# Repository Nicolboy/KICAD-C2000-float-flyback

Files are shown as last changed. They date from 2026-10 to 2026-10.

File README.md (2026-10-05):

# KICAD-C2000-float-flyback

- **18.9W** — real-world target power, simulated efficiency up to 94.8%
- **+5 points** efficiency from synchronous rectification (UCC24612) vs. body-diode
- **106.8V → 61–65V** — secondary overvoltage, resolved by a TVS clamp sized through simulation (×1.5 margin vs. the 100V MOSFET rating)

Isolated, floating-secondary flyback power supply for vacuum-tube filament
heating and a low-noise preamp stage, designed in KiCad 10. 200kHz,
11–25V in → 5.5–13V/3A out, secondary floating and liftable 0–90V for
cathode/filament stress reduction. Synchronous secondary rectification
(UCC24612, direct Vds sensing — no firmware timing) validated by SPICE at
the real 18.9W target, including a secondary-side overvoltage finding and
the clamp that fixes it — see *Validation* below for the figures and
`doc/sim-vs-mesure.md` for the full data.

Alimentation flyback isolée et flottante pour le chauffage d'un filament de
tube à vide et un étage de préamplification bas bruit, conçue sous KiCad 10.

Convertisseur flyback 200kHz, 11-25V en entrée → 5,5-13V/3A en sortie.
Secondaire entièrement flottant, élevable de 0 à 90V par un pont symétrique
2×100kΩ (une résistance vers Vout+, une vers Vout-) — pour réduire le stress
cathode/chauffage sur un préamplificateur à tubes bas bruit (montage cascode).

<p align="center">
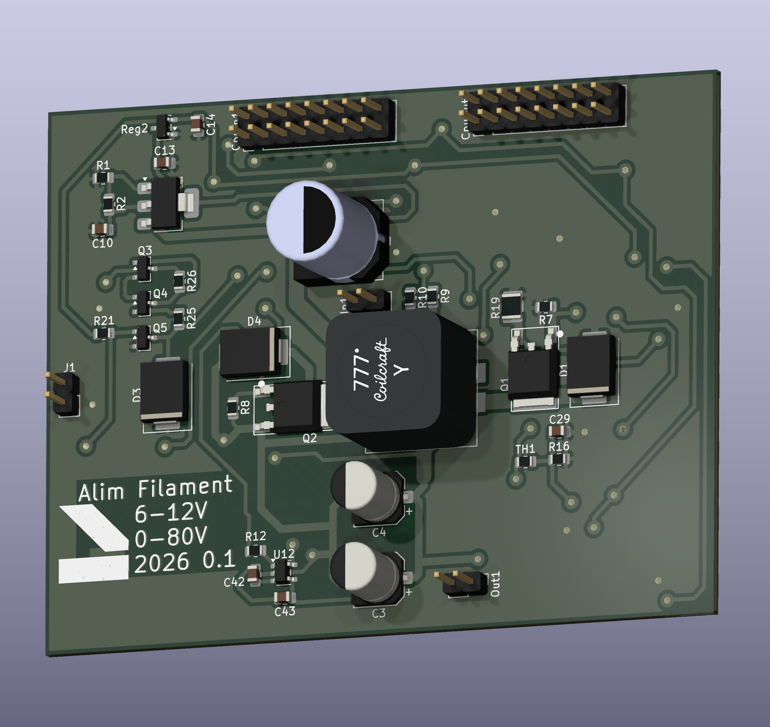
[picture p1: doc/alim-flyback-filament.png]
Rendu 3D de la carte d'alimentation flyback KiCad
  
</p>

---

## Le point de conception le plus notable

Le redressement synchrone secondaire (Q2) est piloté par un **UCC24612**, pas
par le C2000 : ce contrôleur détecte directement le Vds de Q2 (diode
emulation) et pilote sa grille tout seul — aucun signal PWM ni isolateur
dédié à faire traverser la barrière pour ce canal. Avant ça, la commande
passait par un ISO7710+UCC27517 secondaires pilotés en PWM depuis le C2000 :
un timing fixé par le firmware, « à l'aveugle », sans retour sur le vrai Vds
de Q2 — remplacé une fois ce défaut identifié. L'UCC24612 est alimenté
directement depuis Vout (VDD dans sa plage 4,5-28V, pas de bootstrap
nécessaire) ; côté primaire, l'isolation PWM/EN (ISO7710 + UCC27517 + DPC817)
reste inchangée.

Chaque composant de puissance (MOSFETs, clamp, condensateurs d'entrée et de
sortie) est sourcé avec sa propre fiche datasheet dans
[`composants-datasheets/data/carte-flyback/`](../composants-datasheets/data/carte-flyback)
— page citée, base (absolue / recommandée / typique / calculée), jamais de
valeur choisie à l'oeil. Ce sourcing a d'ailleurs fait revenir deux fois sur
le choix de Cin et Cout : le premier calcul prenait le coin 13V/3A (39W)
comme pire cas, avant d'être recorrigé sur les vrais coins d'usage — deux
câblages de filament qui tombent à **la même puissance réelle** (18,9W) et
divisent par deux la contrainte de courant et d'ondulation retenue au départ.
Le détail (formules, marges, historique des choix) est dans
[`00-intention-conception.md`](00-intention-conception.md).

---

## Architecture

| Bloc | Rôle |
|---|---|
| Primaire | Cin, MOSFET N (TO-252), clamp TVS D1 (boîtier SMC), UCC27517 + ISO7710 (PWM) |
| Isolation | ISO7710 (PWM primaire) + DPC817 (EN) — plus de canal PWM dédié au secondaire |
| Secondaire (flottant) | MOSFET N potentiel bas (rectification synchrone), UCC24612 (détection Vds, alimenté direct depuis Vout) + clamp TVS D4, banc Cout, pont bias 2×100kΩ |
| Couplage | Coilcraft MSD1514, 1:1 (k≈0,99), 10µH par enroulement |

L'isolation fonctionnelle est dimensionnée pour l'écart réel présent sur la
carte (~100V avec le bias), pas pour la tenue diélectrique complète des
isolateurs (5000V) — pas de slot d'isolation dans le PCB.

---

## Le schéma est généré, les feuilles sont ensuite routées à la main

```
00-intention-conception.md      source de vérité (calculs, marges, sourcing)
        │
        ├── gen_symboles.py        → lib/custom_parts.kicad_sym
        │                            (UCC27517, ISO7710, MSD1514, MOSFET 3 broches)
        │
        └── gen_composants.py      → alim.kicad_sch / flyback.kicad_sch /
              ▲                       isolation.kicad_sch (feuilles hiérarchiques)
              │                       kicad_gen.py — primitives communes
        étiquettes globales uniquement, aucun fil posé par script
```

Une fois qu'une feuille a été reprise à la main dans KiCad (repositionnement
des composants, rotation, déplacement des étiquettes Référence/Valeur), elle
devient un **fichier de travail permanent** : les générateurs ne sont plus
rejoués dessus.

ERC sur la hiérarchie complète des 3 feuilles : 0 erreur. Empreintes custom
(`lib_fp/*.pretty/`) pour l'inductance couplée MSD1514, le MOSFET TO-252 et le
condensateur KEMET A786MW (V-chip), toutes construites à partir des cotes
mécaniques des datasheets plutôt que d'une empreinte générique approximative.

Placement et routage du PCB restent manuels, comme pour les autres cartes de
ce workspace.

---

## Validation — simulation et mesure

| Étape | État |
| --- | --- |
| Calcul analytique | fait — [`00-intention-conception.md`](00-intention-conception.md) |
| Simulation LTspice (diode, 10W) | étapes 1-4 faites, modèles réels (MOSFET Infineon, clamp D1) |
| Simulation LTspice (18,9W, synchrone) | faite — proxy UCC24612, clamp secondaire dimensionné |
| Redressement synchrone (KiCad) | implémenté — UCC24612 (U12) + clamp D4 |
| Prototype | à fabriquer |
| Mesures au banc | à faire |

Balayage à Vin=11/20/25V, 6V et 12V à 10W (+ un point à charge légère) :
rendement 84-91%, et la tension drain de Q2 dépasse déjà 100V (sa tenue
en tension) à Vin≥23V environ, sans clamp secondaire modélisé à ce
stade.

<p align="center">
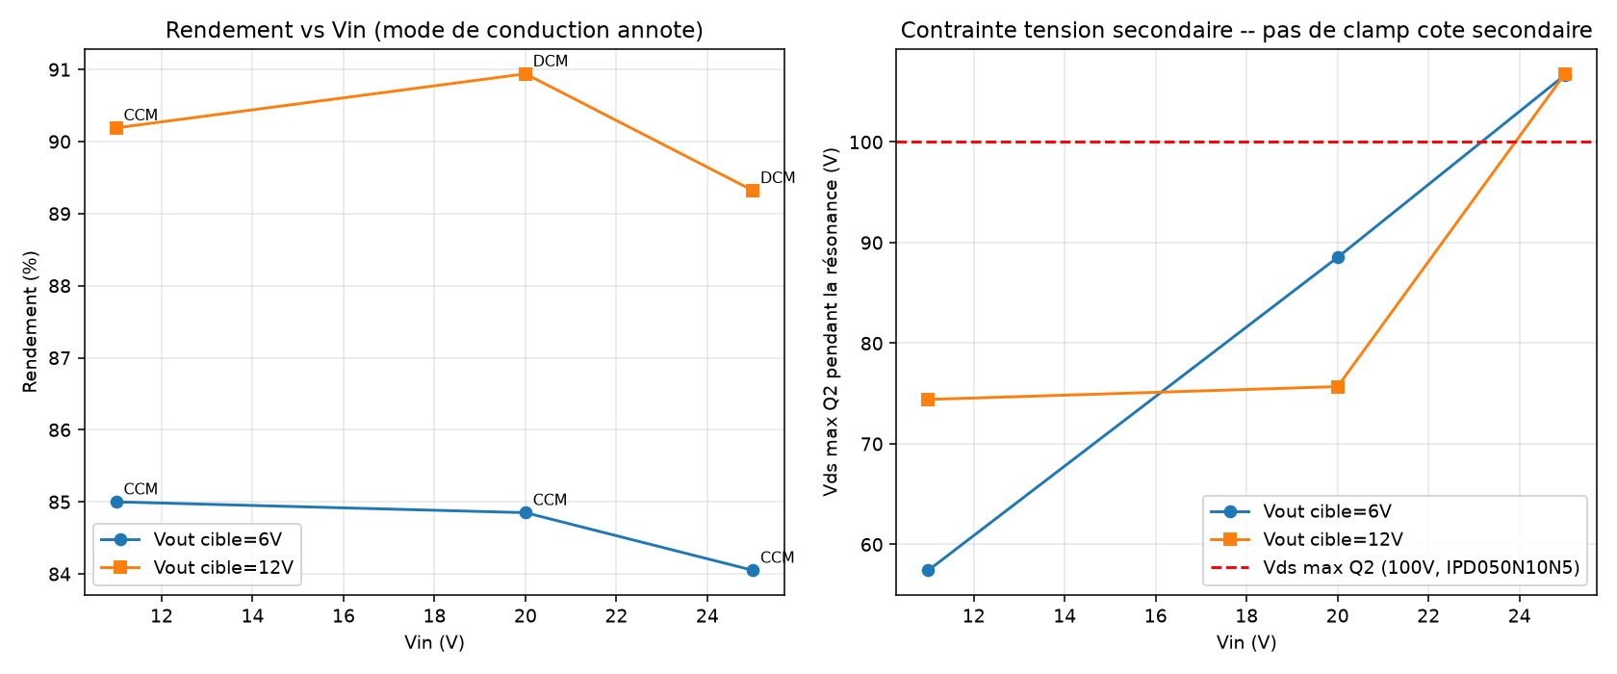
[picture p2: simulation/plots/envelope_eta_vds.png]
Rendement et Vds Q2 vs Vin, 10W, redressement par diode de corps
  
</p>

Autre résultat notable : la plupart des points réels fonctionnent en
**CCM**, pas en DCM comme une estimation rapide l'avait d'abord suggéré —
déterminé sur la forme d'onde (passage par zéro de I(L2)), pas supposé.
Comparé à un modèle Schottky générique simplifié (rapide mais pas le
composant réel) pour chiffrer la perte dans le clamp D1 :

<p align="center">
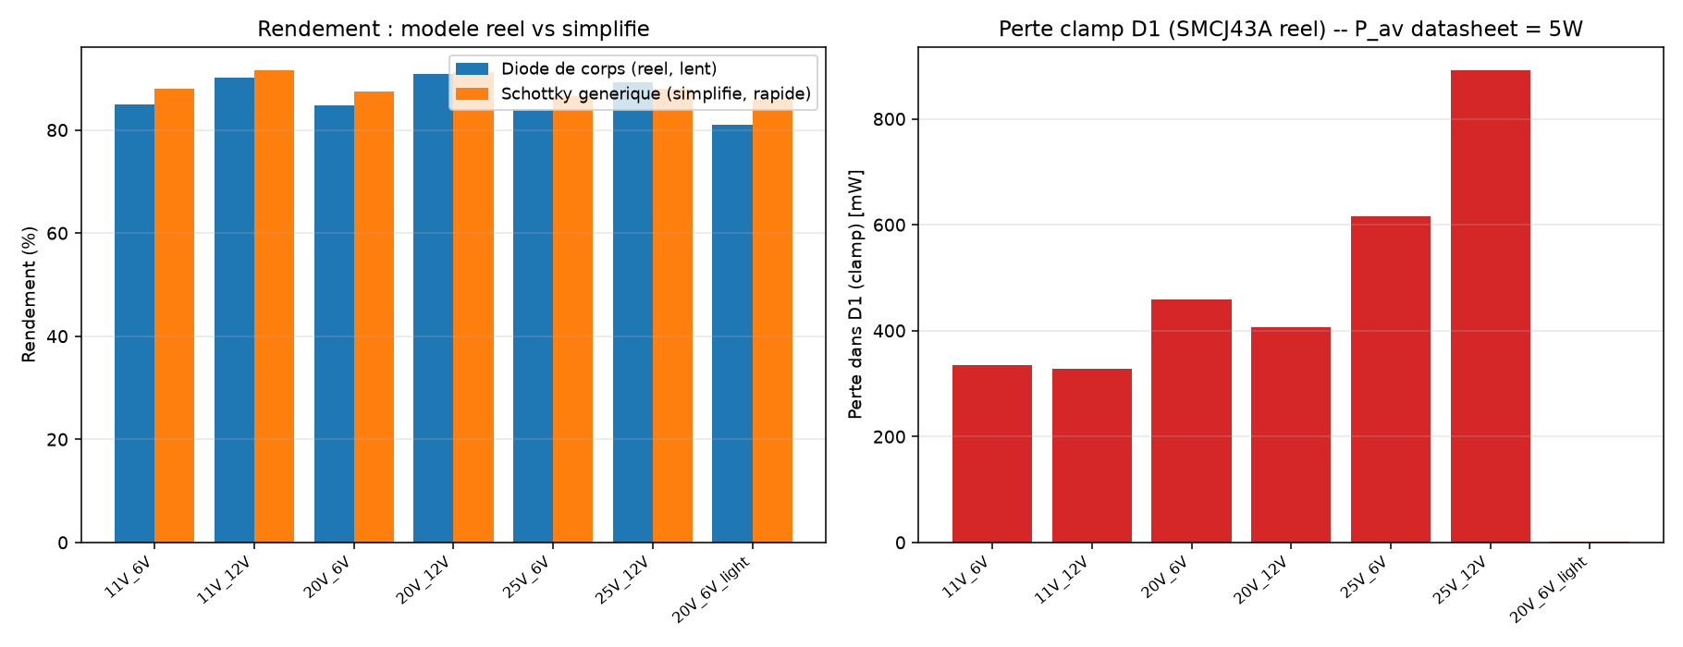
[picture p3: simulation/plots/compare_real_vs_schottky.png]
Rendement modele reel vs simplifie, et perte dans le clamp D1
  
</p>

Rejoué à la cible réelle (**18,9W**) avec un proxy de redressement
synchrone : le dépassement empire (dès Vin=20V, jusqu'à 106,8V) —
indépendant du redresseur, c'est une résonance de l'inductance de fuite.
Le passage en synchrone (UCC24612) apporte jusqu'à +5 points de
rendement, mais ne corrige pas la surtension :

<p align="center">
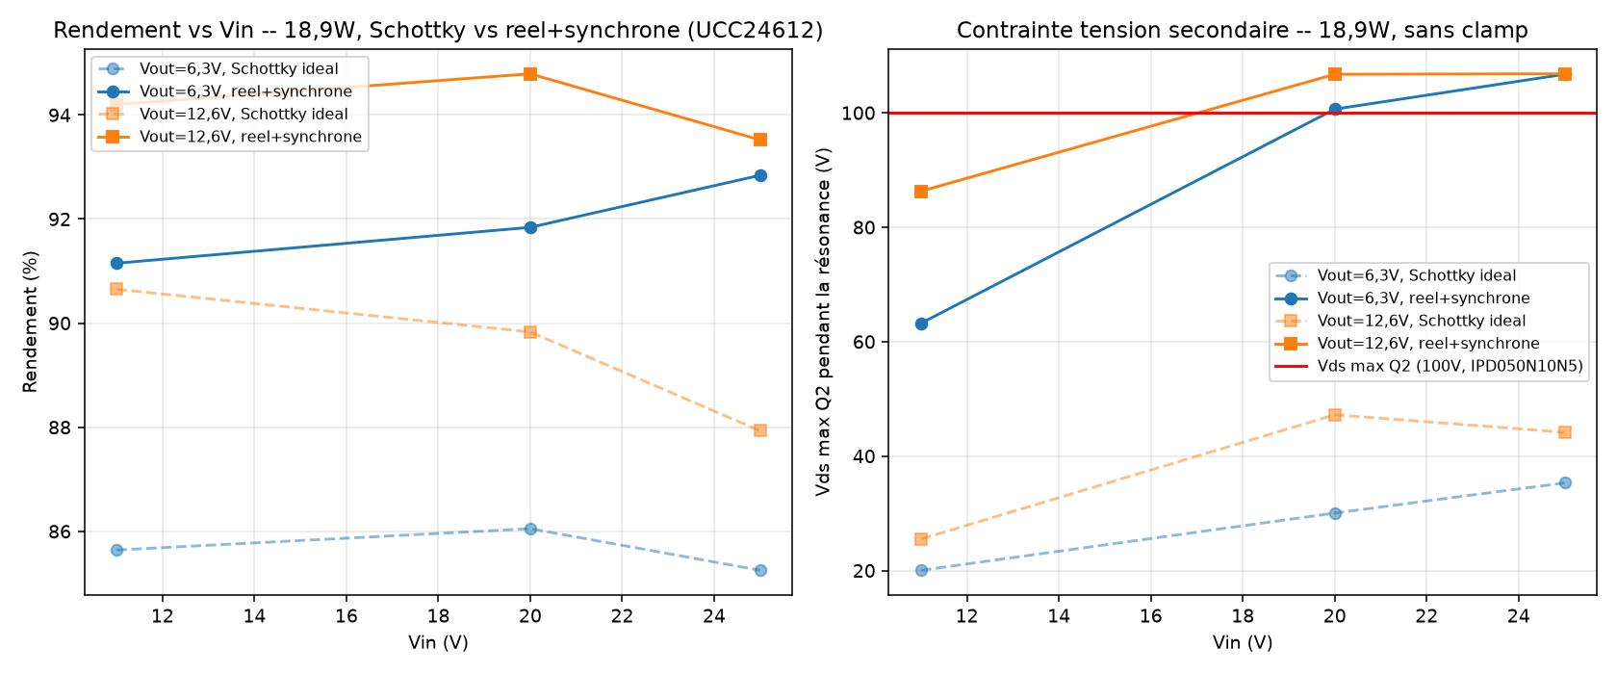
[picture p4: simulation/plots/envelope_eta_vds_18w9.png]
Rendement et Vds Q2 vs Vin, 18,9W, Schottky vs reel+synchrone
  
</p>

D'où le clamp secondaire **D4 (SMCJ54A)**, qui ramène Vds_Q2 à 61-65V
(marge ×1,5) pour 0,03-0,76W de dissipation (marge ×6,6 vs les 5W du
composant) — comparé au SMCJ43A (même réf. que D1, déjà au BOM) qui tient
aussi mais coûte jusqu'à 2 points de rendement de plus :

<p align="center">
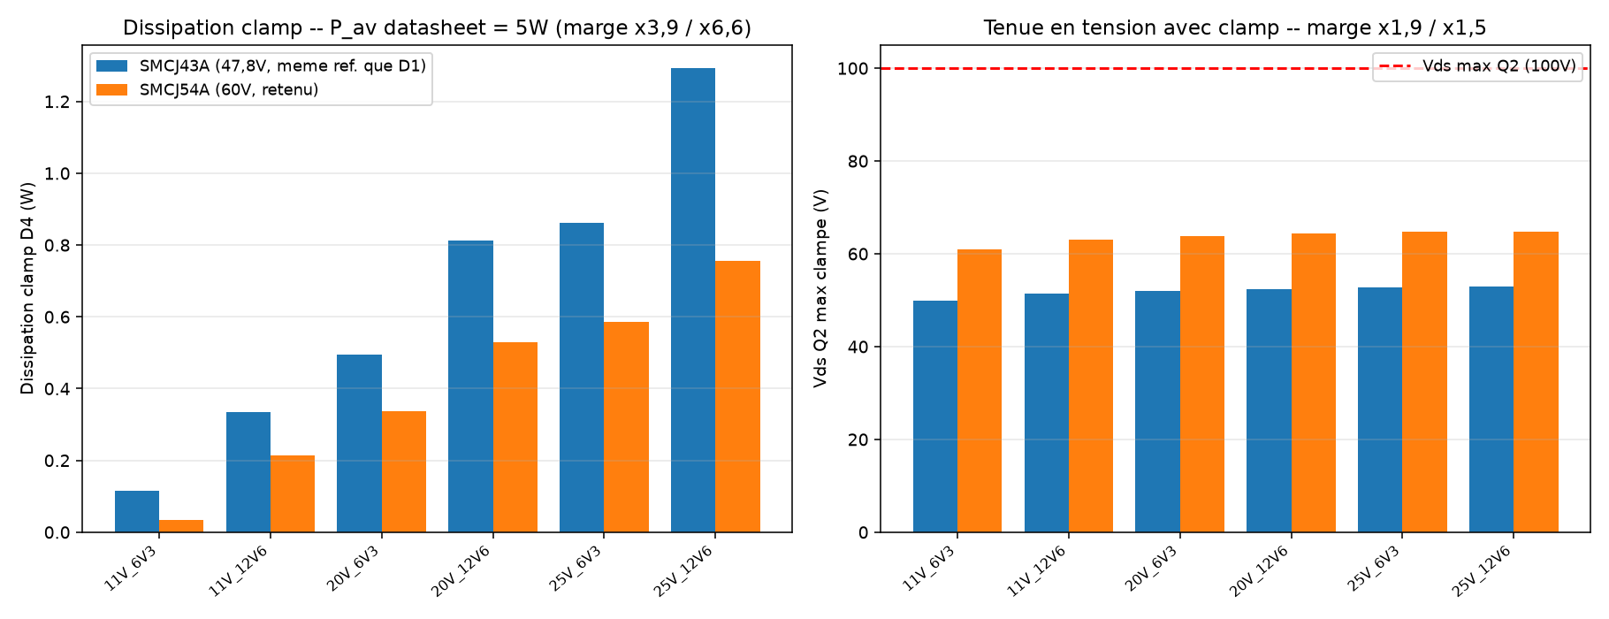
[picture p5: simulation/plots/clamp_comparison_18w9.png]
Comparaison clamp secondaire SMCJ43A vs SMCJ54A, dissipation et tenue en tension
  
</p>

Le détail, le protocole de mesure et le tableau calcul / simulation /
mesure : [`doc/sim-vs-mesure.md`](doc/sim-vs-mesure.md) (§7/§7bis pour le
passage 18,9W) ; l'implémentation KiCad correspondante :
[`00-intention-conception.md`](00-intention-conception.md) §16.

---

## Licence

CERN-OHL-S v2 — voir [`LICENSE`](LICENSE).

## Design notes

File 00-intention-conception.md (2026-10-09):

# Intention de conception — flyback flottant filament + préampli

| | |
|---|---|
| Révision | v0.8 — redressement synchrone secondaire réel : UCC24612 (U12) remplace U2/U4, clamp D4 ajouté |
| Établi le | 2026-09-28, mis à jour 2026-10-04 |
| Statut | duty cycle et courants inductance vérifiés ; clamp TVS SMC et filtrage de sortie 50mV tranchés (§6, §7) ; retour ADC isolé AMC0311S ajouté (§13) ; UCC5304 essayé puis abandonné côté secondaire, marge UVLO insuffisante pour un filament réglable (§13bis) ; retours température MOSFET/transfo et courant primaire ajoutés, isolateurs migrés vers la famille ratiométrique AMC03x1R/AMC03x2R (§14) ; isolation C2000 rendue réelle — U3/U4/U5/U7/U8/U9 migrés sur GND_CTRL/3V3_CTRL, connecteur scindé CpuOut/CpuIn (§15) ; nouvelle feuille Polarisation — HV_BIAS piloté activement 0-78V utiles depuis une source 80V externe fixe, connecteurs C2000 agrandis à 16 broches (§16) ; cible 18,9W validée par simulation sous réserve d'un clamp secondaire, U2(UCC27517)+U4(ISO7710) remplacés par U12(UCC24612, détection Vds) + D4(SMCJ54A) (§17) |

Convention reprise de `composants-datasheets/CLAUDE.md` : `spec` = exigence
d'entrée · `déduit` = calculé · `?` = à trancher. Toute valeur `déduit` porte
sa formule et sa source.

## 1. Fonction

Flyback isolé flottant, 200kHz, alimentant un filament de chauffage tube +
étage de préamplification bas bruit. Secondaire flottant, élevable de 0 à
90V par pont 2×100k symétrique (Vout+/Vout- vers la source HV externe).

## 2. Grandeurs par nœud

| Nœud | Nominal | Max | Statut |
|---|---|---|---|
| `Vin` | 11 – 25 V | 25 V | spec |
| `Vout` | 5,5 – 13 V | 13 V | spec |
| `Iout` | — | 3 A | spec |
| `f_sw` | 200 kHz | — | spec |
| Bias secondaire (vers HV externe, 2×100k) | 0 – 90 V | 90 V | spec |

**Charge réelle — spec.** 10 filaments de tube préampli standard (12AX7 ou
EF86), câblage variable :

| Câblage | Vout | Iout | Pout |
|---|---|---|---|
| Parallèle | 6,3 V | 3 A | 18,9 W |
| Série (paires) | 12,6 V | 1,5 A | 18,9 W |

Les deux corners tombent à la **même puissance** (charge résistive de
filament à puissance constante). C'est ce couple qui pilote les calculs de
courant et de dissipation ci-dessous — **pas** le coin 13V/3A (39W) utilisé
en v0.1, qui surestimait largement la contrainte réelle. Le plafond `Vout
max = 13V` de la spec reste néanmoins la référence pour le dimensionnement
en **tension** (§5) : rien n'indique que 13V soit exclu, seulement que le
courant n'y atteint pas 3A dans l'usage prévu.

## 3. Étage primaire — duty cycle et courants

Coupled inductor MSD1514-103ME, 1:1 (k≈0,99), L=10µH chaque enroulement —
`datasheets/inductors/msd1514.pdf` p.2, tbl produit.

Rapport cyclique (1:1, pertes de diode ignorées au premier ordre) :
`D/(1-D) = Vout/Vin`

| Vin | Vout | D | Statut |
|---|---|---|---|
| 25 V | 6,3 V | 0,201 | déduit |
| 11 V | 12,6 V | 0,534 | déduit |
| 11 V | 6,3 V | 0,364 | déduit |

**Coin de pire cas retenu pour le courant primaire : Vin=11V (le plus
défavorable, courant d'entrée le plus élevé à puissance donnée), comparé
sur les deux câblages réels.**

Hypothèse de rendement **η=0,85** — **non sourcée, à vérifier au banc**,
basis: computed/assumed. C'est l'hypothèse la plus sensible de ce paragraphe.
Pin = 18,9 / 0,85 = 22,24 W dans les deux cas (même Pout).

```
                              Câblage 6,3V/3A    Câblage 12,6V/1,5A
D (à Vin=11V)                 0,364               0,534
Iin_avg = Pin/Vin              2,02 A              2,02 A
I_on_avg = Iin_avg/D            5,55 A              3,79 A
ΔI = Vin×D×T/L                  2,00 A              2,94 A
Ipk = I_on_avg + ΔI/2            6,55 A              5,25 A
Ivalley = I_on_avg − ΔI/2         4,55 A              2,32 A
I_on_rms                          5,58 A              3,88 A
I_primaire_rms = I_on_rms×√D        3,37 A              2,84 A
```

**Le câblage 6,3V/3A est le coin le plus contraignant** (Ipk et Irms les
plus élevés) — c'est lui qui pilote le clamp (§6) et le MOSFET primaire.

**Vérification vs MSD1514-103ME.** Le datasheet donne deux colonnes Irms :
« both windings » (5,4A) et « one winding » (7,6A) — la première vise les
topologies à conduction simultanée des deux enroulements (SEPIC/Zeta,
diagrammes typiques du même datasheet p.1), la seconde le flyback où les
deux enroulements conduisent en alternance, jamais ensemble. **C'est la
colonne « one winding » qui s'applique ici** (le flyback est un des schémas
typiques donnés pour ce composant, doc 1308-1 p.1).

| | Calculé (coin 6,3V/3A) | Limite (one winding) | Marge |
|---|---|---|---|
| Irms primaire | 3,37 A | 7,6 A | ×2,26 |

Marge large, pas de point dur sur l'inductance côté courant. Isat au pire
cas (Ipk=6,55A) est très en dessous de Isat-10% (12,2A) — pas de
saturation.

## 4. Étage secondaire — courants

Secondaire 1:1, conduction complémentaire du primaire (jamais simultanée).
Par continuité du flux (couplage k≈0,99), le courant secondaire démarre à
Ipk et redescend à Ivalley sur la durée (1-D)×T. Au coin dimensionnant
(6,3V/3A, Vin=11V, D=0,364) :

```
I_off_rms = même formule que I_on_rms = 5,58 A  (mêmes Ipk/Ivalley, durée différente)
I_secondaire_rms = I_off_rms × √(1-D) = 5,58 × √0,636 = 4,45 A
```

| | Calculé | Limite (one winding) | Marge |
|---|---|---|---|
| Irms secondaire | 4,45 A | 7,6 A | ×1,71 |

## 5. Contrainte en tension MOSFET primaire

Dimensionnement en **tension** : référencé au plafond de spec (13V), pas
au coin de charge réel — la tenue en tension ne dépend pas du courant tiré
à cette tension.

```
Vds_regime = Vin_max + Vout_max_reflected(1:1) + Vf_redresseur
           = 25 + (13 + 1) = 39 V     (Vf=1V, hypothèse diode de corps en phase bootstrap)
```

Reste à ajouter la surtension de commutation due à l'inductance de fuite
(0,40µH typ, même tableau datasheet) — voir §6, elle fixe le niveau de
clamp et donc la tenue en tension à viser pour le MOSFET.

## 6. Clamp primaire — TVS SMC, tranché

Énergie de fuite par cycle, au coin de charge réel dimensionnant
(6,3V/3A, Ipk=6,55A — §3) :

```
E_fuite = ½ × L_fuite × Ipk² = 0,5 × 0,40µH × 6,55² = 8,59 µJ
P_clamp = E_fuite × f_sw = 8,59µJ × 200kHz ≈ 1,72 W
```

Nettement plus raisonnable que l'estimation v0.1 (3,4W, basée sur le coin
13V/3A surestimé). **1,7W est tenable par un TVS en boîtier SMC/DO-214AB**
avec un cuivre de dissipation correct — décision retenue : **TVS/zener,
boîtier SMC**. Tension de claquage à sourcer pour couvrir les 39V de
Vds_regime (§5) avec marge de clamp, sans dépasser la tenue en tension du
MOSFET primaire retenu.

## 7. Filtrage de sortie — banc de condensateurs, tranché

Cible relâchée à **50mV** d'ondulation crête-crête max (décision utilisateur),
Iout et D pris au coin de charge réel dimensionnant (6,3V/3A, D=0,364,
Ipk=6,55A — §3, plus contraignant que 12,6V/1,5A).

**Composante capacitive** (le cap seul alimente la charge pendant Ton) :
```
ΔQ = Iout × D × T = 3 × 0,364 × 5µs = 5,46 µC
Pour ΔV_C = 20mV (part du budget) : C = ΔQ / ΔV_C ≈ 273 µF
```

**Composante ESR** (démonstration : le saut de courant dans le
condensateur vaut Ipk à l'ouverture, Ivalley à la fermeture — le premier
domine ; ΔV_ESR,pk-pk = ESR × Ipk, formule standard flyback, pas les 9,2A
de battement grossièrement estimés en v0.1) :
```
Pour ΔV_ESR = 30mV (reste du budget) : ESR_max = 30mV / 6,55A ≈ 4,6 mΩ
```

**4,6mΩ est atteignable par un petit banc de condensateurs polymère bas
ESR en parallèle** (ESR unitaire typique 10-15mΩ en boîtier CMS courant →
2 à 3 en parallèle suffisent, ESR combiné = ESR_unitaire / N). Décision
retenue : **banc de 2-3 condensateurs polymère CMS en parallèle**, cible
combinée ESR ≤ 4,6mΩ et C ≥ 273µF. Références précises à sourcer (§ sourcing
composants).

## 8. Condensateurs — Cin, Cout, Cboot, tranchés

**Cin** (entrée, coin de charge réel 6,3V/3A, D=0,364, §3) :

```
I_on_rms = 5,58A, I_on_avg = 5,55A  (§3)
Icin_rms = √(D×(I_on_rms² − D×I_on_avg²))
         = √(0,364×(5,58² − 0,364×5,55²)) = 2,69A
```

Première solution retenue : 2× UCM1V222M1MS (Nichicon UCM, 2200µF/35V,
45mΩ) — 4,12A de marge ripple mais 22,5mΩ combiné, soit ~149mV
d'ondulation d'entrée réelle (calcul complet ci-dessous, pas de cible
formelle contrairement à la sortie). **Remplacée** (utilisateur,
2026-09-29) par **1× KEMET A786MW477M1VLAV010** (hybride polymère,
470µF/35V, ESR=10mΩ) —
`composants-datasheets/data/carte-flyback/a786mw477m1vlav010.yaml` :

```
ΔV_ESR = 10mΩ × 6,553A (Ipk, §3)                         ≈ 65,5mV
ΔV_C   = (I_on_avg−Iin_avg)×D×T / C = 3,532A×0,364×5µs/470µF ≈ 13,7mV
Total  ≈ 79,2mV — contre 148,9mV avec l'ancienne solution (2×UCM)
```

Un seul exemplaire suffit (comparé à l'option 2× qui donnait 39,6mV — écartée
par l'utilisateur au profit d'un seul composant). Ripple current très
large marge (5,6A@125°C vs 2,69A requis, ×2,08). Marge tension ×1,4 (35V
vs 25V Vin_max), identique à l'ancienne solution.

**Cout** (sortie, cible relâchée à 50mV — décision utilisateur du
2026-09-28, coin de charge réel 6,3V/3A, Ipk=6,55A, D=0,364, §3) :

```
ΔQ = Iout×D×T = 3×0,364×5µs = 5,46µC
ΔV_ESR(N) = (ESR_unitaire/N) × Ipk        ΔV_C(N) = ΔQ/(C_unitaire×N)
```

Un électrolytique « low impedance » classique (famille UCM, ~24-45mΩ pour
un gros boîtier) ne permet pas d'approcher l'ESR combiné visé sans un
nombre de boîtiers déraisonnable. Première solution retenue (5×
Panasonic 25SVPF100M, 100µF/25V, ESR=24mΩ) donnait 42,4mV — marge 15%
seulement. **Remplacée** (utilisateur, 2026-09-29) par **2× Panasonic
16SVPG330M** (330µF/16V, ESR=6,5mΩ — le plus bas de sa série) —
`composants-datasheets/data/carte-flyback/16svpg330m.yaml` :

```
ΔV_ESR = (6,5mΩ/2)×6,55A ≈ 21,3mV
ΔV_C   = 5,46µC/660µF    ≈ 8,3mV
Total  ≈ 29,6mV < 50mV — marge 41%. (N=1 donne 59,1mV, insuffisant.)
```

Moins de composants (2 au lieu de 5), meilleure marge d'ondulation, mais
marge en tension plus courte : 16V vs Vout_max=13V = ×1,23 (23%), contre
×1,92 pour l'ancienne solution — acceptée explicitement par l'utilisateur
après avoir vu le calcul.

**Cboot — composant retiré (§17, 2026-10-04), calcul conservé pour mémoire.** (stockage bootstrap secondaire, alimentait UCC27517-secondaire en direct + MCP1703 en amont de l'ISO7710-secondaire — architecture validée avec l'utilisateur en amont de cette session)
direct + MCP1703 en amont de l'ISO7710-secondaire — architecture validée
avec l'utilisateur en amont de cette session) :

```
Qg(IPB020N10N5) = 210nC (max, composants-datasheets/data/carte-flyback/ipb020n10n5.yaml)
Iq(UCC27517+MCP1703+ISO7710) ≈ 5mA (ordre de grandeur, non individuellement sourcé)
Intervalle de décharge = Ton (primaire) au pire cas = D×T = 0,364×5µs = 1,82µs
ΔQ ≈ Qg + Iq×Ton ≈ 210nC + 5mA×1,82µs ≈ 219nC
Pour ΔV_droop = 200mV (marge sous l'hystérésis UVLO UCC27517, 300mV typ) :
C_boot = ΔQ/ΔV ≈ 1,1µF minimum
```

Retenu : **4,7µF X7R 0805, 25V** — céramique standard (pas de fiche
sourcée séparée : composant passif générique, cohérent avec la pratique du
reste du dépôt pour le découplage). Marge large même avec déclassement en
tension continue typique du X7R (effective ~2-3µF sous polarisation
~6-12,5V, encore ≥ le minimum calculé).

## 9. Alimentation auxiliaire primaire — ajout non prévu dans la spec initiale

En construisant le schéma, un trou est apparu : rien n'alimente l'UCC27517
et l'ISO7710 côté **primaire** (référencé masse, pas de problème de
flottement contrairement au secondaire, mais Vin=11-25V dépasse la plage
recommandée de l'UCC27517 — 4,5-18V — et l'absolu de l'ISO7710 — 5,5V max).
Il faut une alim auxiliaire primaire, absente de la spec initiale.

Repris à l'identique du montage déjà en service sur l'autre carte de ce
workspace (`00-intention-conception-v12.md` §7/§10, dual-boost) : **LM317M
+ pont 100Ω/560Ω → 8,25V** pour l'UCC27517-primaire (`data/carte-puissance/
lm317m.yaml`, déjà sourcé — repris pour `carte-flyback` avec ses propres
repères), puis **MCP1703-3302 en cascade depuis ce rail 8,25V** (déjà
sourcé pour le secondaire, `data/carte-flyback/mcp1703.yaml`) → 3,3V pour
l'ISO7710-primaire. Deux avantages à cascader plutôt que deux régulateurs
depuis Vin directement : le MCP1703 n'a plus à encaisser les 25V de Vin_max
(son propre Vin_max est 16V, insuffisant en direct), et aucun nouveau
composant à sourcer.

```
Vout(LM317M) = 1,25×(1+R2/R1) = 1,25×(1+560/100) = 8,25V   (mêmes valeurs que l'autre carte)
Différentiel au point bas : Vin_min − Vout = 11 − 8,25 = 2,75V
```

Sous le dropout min publié (3,0V, `lm317m.yaml`) — **même marge que l'autre
carte**, qui traite déjà ce point comme acceptable (« clôt la question du
dropout » dans son propre document d'intention). Pas retranché ici.

Dissipation estimée (Q1 Qg=72nC×200kHz≈14,4mA + ISO7710 primaire ~1,7mA +
marges ≈20mA) : P=(25−8,25)×20mA≈0,34W. Avec Rth_ja=245°C/W (boîtier
SOT-223, empreinte minimale — même valeur élevée déjà notée comme
suspecte sur l'autre carte) : ΔT≈82°C, Tj≈107°C à 25°C ambiant — chaud
mais sous Tj_max=150°C. Cuivre de dissipation à soigner au routage, comme
sur l'autre carte.

## 10. Composants sourcés — récapitulatif

| Rôle | Réf. | Composant | Fiche |
|---|---|---|---|
| MOSFET primaire+secondaire | Q1, Q2 | IPD050N10N5 (TO-252/DPAK, 100V, 5mΩ) | `data/carte-flyback/ipd050n10n5.yaml` |
| Empreinte Q1/Q2 | — | `lib_fp/TO252.pretty/TO252-3_TabPin2.kicad_mod`, custom (3 pastilles, cotes Figure 1 du datasheet IPD050N10N5 fournies par l'utilisateur) — remplace la générique KiCad jugée peu lisible (4 pastilles). **Pin1(Gate)/Pin3(Source) permutées (2026-10-01)** — voir point ouvert résolu ci-dessous. Modèle 3D (2026-10-01) : d'abord le `.step` fourni avec KiCad (miroir corrigé par `scale -1 1 1`), puis **remplacé** par `composants-datasheets/datasheets/to_252_2.step` (step.parts.com, 3 broches + tab, boîtier compact — fourni par l'utilisateur). Transform identité par défaut, alignement à confirmer dans le visualiseur 3D (pas de rendu possible de mon côté) |
| Clamp primaire | D1 | SMCJ43A (SMC/DO-214AB) | `data/carte-flyback/smcj43a.yaml` |
| Rail 8,25V primaire | Reg1 | LM317M (SOT-223) + R1=100Ω/R2=560Ω | `data/carte-flyback/lm317m.yaml` |
| LDO ISO7710 primaire | Reg2 | MCP1703-3302 (SOT-23A, 3,3V) | `data/carte-flyback/mcp1703.yaml` |
| LDO auxiliaire secondaire | Reg3 | MCP1703-3302 (SOT-23A, 3,3V) — VI depuis VOUT_P direct (§17), alimente VDD1 de U7 (AMC0311R) | `data/carte-flyback/mcp1703.yaml` |
| Cin | C1 | A786MW477M1VLAV010 (KEMET, 470µF/35V, 10mΩ) | `data/carte-flyback/a786mw477m1vlav010.yaml` |
| Cout | C3, C4 | 2× Panasonic 16SVPG330M (330µF/16V, 6,5mΩ) | `data/carte-flyback/16svpg330m.yaml` |
| Ampli isolé retour Vout | U7 | AMC0311R (DWV-8, ratiométrique) — retour Vout isolé vers C2000 (§13, renommé depuis AMC0311S en §14) | à sourcer (`composants-datasheets/data/carte-flyback/amc0311r.yaml`, session dédiée) |
| Empreinte U7/U8/U9 | — | `lib_fp/SOIC_DWV.pretty/SOIC-8_DWV_5.85x11.5mm_P1.27mm.kicad_mod`, custom (boîtier DWV renforcé, cotes land pattern fournies par l'utilisateur) — modèle 3D `DWV0008A.stp` fourni par l'utilisateur, transform identité à affiner (§14) |
| Thermistance temp. primaire | TH1 | NTC 10k/B=4000, 0805 | non sourcé séparément (§14) |
| Ampli isolé retour température | U8 | AMC0311R (DWV-8, ratiométrique) — retour température primaire isolé vers C2000 (§14) | à sourcer |
| Shunt courant primaire | R19 | 1210, valeur provisoire 7,5mΩ | à sourcer (valeur et dissipation, §14) |
| Ampli isolé retour courant | U9 | AMC0302R (DWV-8, ratiométrique, ±50mV) — retour courant primaire isolé vers C2000, protection surcourant Q1 (§14) | à sourcer |
| Redressement synchrone secondaire | U12 | UCC24612 (SOT23-5) — remplace U2(UCC27517)+U4(ISO7710), détection Vds (§17) | à sourcer (`datasheets/ucc24612.pdf` déjà présent, pas encore de yaml) |
| Clamp secondaire | D4 | SMCJ54A (SMC/DO-214AB, même boîtier/famille que D1) — dimensionné `doc/sim-vs-mesure.md` §7bis (§17) | à sourcer (`datasheets/bourns-smcj-series.pdf` déjà présent, pas encore de yaml) |
| Découplage U12 | C42, C43 | 2,2µF (REG) + 100nF (VDD, bypass HF local) (§17) | non sourcé séparément, générique comme Cboot |

## 11. Points ouverts

- [ ] Rendement η=0,85 utilisé en §3 — hypothèse, à vérifier au banc
- [ ] Vf du redresseur secondaire en phase bootstrap (§5) — 1V pris par
      hypothèse. IPD050N10N5 (sourcé, Q2) donne Vf_body_diode=1,2V max à 40A
      (très au-dessus du courant réel ~6,55A) — conforte l'hypothèse comme
      raisonnablement conservatrice.
- [x] Diode de bootstrap secondaire (Vout → Cboot) — **devenue sans objet** :
      Cboot et le bootstrap associé sont retirés (§17), Reg3 (MCP1703) est
      câblé directement sur VOUT_P, plus de diode ni de chute Vf dans ce
      chemin
- [x] **Pin1(Gate)/Pin3(Source) de l'empreinte TO252-3_TabPin2 étaient
      permutées** (2026-10-01) — la réserve initiale du fichier
      d'empreinte (« pin1=haute/pin3=basse, pas confirmé par capture
      photo ») était fondée. L'utilisateur a fourni un croquis Infineon
      TO220/DPAK (languette en haut, broches 1-2-3 gauche-à-droite,
      1=Gate/2+tab=Drain/3=Source). Recalcul géométrique : en tournant la
      pièce réelle pour amener la languette à gauche (notre disposition),
      Gate doit tomber en bas-droite et Source en haut-droite — l'inverse
      de ce qui était posé. Pastilles 1 et 3 permutées (tab/pin2 inchangé).
      **À confirmer malgré tout sur pièce réelle avant premier reflow**,
      même règle que pour toute empreinte custom de ce dépôt (R15,
      `composants-datasheets/CLAUDE.md`).
- [x] Pertes de conduction Q1/Q2 — résolu par le passage en TO-252
      (IPD050N10N5, 2026-09-28) : Rds_on max 5mΩ contre 77mΩ pour l'ancien
      IRF540S. Pertes recalculées négligeables (~113-198mW, ΔT≈15°C même en
      empreinte minimale) — l'ancien point dur (1,75W, proche de la limite
      D2PAK) n'existe plus.
- [ ] Snubber/clamp éventuel côté secondaire (Q2 voit aussi une surtension
      de commutation, cf. plan initial) — pas encore traité, à revoir avant
      le routage final
- [x] Empreinte MSD1514 — corrigée (`lib_fp/MSD1514.pretty/MSD1514.kicad_mod`)
      à partir d'un crop fourni par l'utilisateur du « Recommended Land
      Pattern » (doc 1308-3 p.3), lu directement plutôt que ré-interprété
      depuis une vue pleine page. Mes deux premières lectures (pastilles
      4,2×2,8mm, différentes valeurs de pas) étaient fausses. Valeurs
      retenues : **pastilles carrées 3,7×3,7mm, pas X=7,9mm/Y=6,0mm**,
      dérivées de gapX=4,2mm/gapY=2,3mm avec vérification croisée
      (pitch−gap = 3,7mm des deux côtés). Numérotation
      pin3=haut-gauche/pin2=haut-droite/pin4=bas-gauche/pin1=bas-droite,
      lue sur ce même diagramme — **toujours pas confirmée par capture
      photo de la pièce réelle**, à vérifier avant le premier reflow (même
      discipline que R15 de `composants-datasheets/CLAUDE.md`).
- [x] Empreinte A786MW477M1VLAV010 (Cin) — corrigée quatre fois par
      l'utilisateur (2026-09-29) : (1) confusion D×L=footprint vs corps
      cylindrique (V-chip monté vertical, D=10mm de diamètre, L=16,7mm de
      HAUTEUR, pas une dimension de pastille), (2) pas pastilles affiné
      4,6→7,6mm, (3) rectangle à coins coupés ajouté — mal placé au
      premier essai (autour de la pastille), (4) corrigé : le rectangle
      chanfreiné représente l'**implantation totale du composant**
      (10,3×10,3mm, coins coupés côté positif), superposé au cercle D10mm
      (le corps cylindrique) — deux silhouettes silkscreen distinctes, pas
      un contour de pastille. `lib_fp/A786.pretty/A786MW_VChip.kicad_mod`.
- [x] Empreinte MSD1514 — corrigée deux fois (2026-09-29) : première
      lecture du land pattern (pastilles 3,7×3,7mm, pas 7,9×6,0mm)
      fausse ; cotes réelles pastilles 4,6×2,5mm, pas X=12,6mm/Y=3,8mm
      (Y affiné de 3,5 à 3,8mm) — le pas X dépasse le corps 15×15mm
      (pattes gull-wing débordant du corps, normal pour ce boîtier),
      courtyard élargi en conséquence. Numérotation des broches inchangée
      (pin3=HG/pin2=HD/pin4=BG/pin1=BD).
- [ ] Polarité du point de couplage L2 (pin2 vs pin4 du MSD1514, §
      symboles) déduite par symétrie du schéma simplifié du datasheet, pas
      explicitement marquée — à confirmer sur pièce réelle avant simulation.
- [x] Marge VDD de l'UCC5304 au coin bas — **résolu en revenant à
      ISO7710+UCC27517 sur le secondaire** (§13bis) : le plancher réel
      d'usage n'est pas 6,3V mais jusqu'à 5,8V (filament réglable -5 à
      -10% sur 6,3V nominal), ce qui aurait mis VBOOT sous le seuil UVLO
      *garanti* (pas juste recommandé) de l'UCC5304 — voir calcul précis
      §13bis avec les seuils UVLO réels du datasheet (p.8 tbl 6.9).
- [ ] Valeurs du filtre RC en sortie de l'AMC0311S (R15=100Ω, C24=1nF,
      §13) — proposées par défaut (fc≈1,6MHz, n'entame pas la bande
      passante propre de l'ampli ~120kHz), à revoir une fois la spec
      d'entrée de l'ADC côté C2000 connue.
- [ ] R11/R12 (résistances de grille en sortie des UCC, 1Ω/0805) — valeur
      retenue par l'utilisateur directement dans KiCad, pas de calcul de
      dimensionnement tracé ici (amortissement/EMI, ordre de grandeur
      courant pour ce type d'application).

- [ ] **R19 sature l'AMC0302R au coin dimensionnant** — R19 × Ipk = 7,5mΩ × 6,55A ≈ 49,2mV contre ±50mV de pleine échelle (marge 1,6%), au régime nominal retenu comme dimensionnant (§3). U9 sert à la protection surcourant de Q1 (§14) : il doit voir au-dessus du pic nominal pour détecter un défaut, pas s'écrêter dessus. À trancher : R19 plus faible (ex. 5mΩ → 32,8mV, marge ×1,52, dissipation 57mW) ou plage AMC0300R/AMC0202R (±250mV) avec le shunt actuel — pas encore choisi.
- [ ] **Plage de `HV_BIAS` — spec 0-90V (§2) non atteignable avec le rail 80V retenu** (§16) : le courant de polarisation tombe à ~0 au-delà de ~78V (§16bis), accepté explicitement pour le comportement de la source mais pas reporté dans le tableau de spec, qui affiche toujours 90V. D3 (SMCJ100A) clampe à 100V — marge à revérifier contre la valeur retenue. À trancher : abaisser la spec à ~78V, ou lever le rail `HV80_IN` au-dessus de 90V + marge.

## 12. État du projet KiCad

Schéma généré par script (`gen_composants.py`, méthode reprise de
KICAD-C2000-devkit : étiquettes globales uniquement, aucun fil, empreintes posées
sur l'instance). **Restructuré en feuilles hiérarchiques** sur demande de
l'utilisateur (2026-09-28) : une feuille racine (`alim-flyback-filament.kicad_sch`,
3 blocs `(sheet ...)`) + trois sous-feuilles —

| Feuille | Fichier | Contenu | Composants |
|---|---|---|---|
| Alimentation | `alim.kicad_sch` | Connecteurs, Reg1/Reg2/Reg3 (LDO), PWR_FLAG | 17 (initial) |
| Flyback | `flyback.kicad_sch` | Cin, T1, Q1/Q2, clamp D1, bootstrap D2/C8, Cout | 15 (initial) |
| Isolation_Drivers | `isolation.kicad_sch` | UCC27517×2, ISO7710×2, DPC817 (initial) | 9 (initial) |

Les étiquettes globales se relient à travers toute la hiérarchie sans rien
changer au câblage — le découpage est purement organisationnel, suit la
frontière fonctionnelle (et pour partie la frontière d'isolement primaire/
secondaire) plutôt que la connectivité.

**Depuis (2026-09-30), les 3 feuilles sont des fichiers de travail
hand-edited** (placement, câblage et réorganisation faits à la main dans
KiCad par l'utilisateur, plus jamais régénérés par script) — voir §13 pour
le détail des changements les plus récents (UCC5304, AMC0311S, Cpu1).
Composants redistribués entre feuilles par l'utilisateur au passage :
`J1→In1`, `J3→Out1`, `J4→Bias1` (renommés), `Reg3/C11/C12/R9/R10` déplacés
vers Flyback, `J2→Cpu1` déplacé vers Isolation_Drivers, `C1` déplacé vers
Alimentation — connectivité inchangée (les étiquettes globales ignorent la
feuille physique), seule l'organisation visuelle a bougé.

PCB généré avec contour de carte (70×55mm, à ajuster) — placement et
routage sont les étapes manuelles suivantes, comme pour les autres cartes
de ce workspace.

Fichiers : `alim-flyback-filament.kicad_pro/.kicad_sch/.kicad_pcb`,
`lib/custom_parts.kicad_sym`, `kicad_gen.py`, `gen_symboles.py`,
`gen_composants.py` (génération initiale, ne plus rejouer sur les feuilles
hand-edited).

**Modèles 3D des empreintes custom (2026-10-01)** : les trois empreintes
custom (Q1/Q2, T1, C1) ont chacune un `.step` référencé dans leur bloc
`(model ...)`. Source de chaque fichier :
- Q1/Q2 (`TO252.pretty`) : `composants-datasheets/datasheets/to_252_2.step`
  (step.parts.com, 3 broches + tab, boîtier compact)
- T1 (`MSD1514.pretty`) : `composants-datasheets/datasheets/inductors/MSD1514.STEP`
  (modèle fabricant Coilcraft, téléchargé par l'utilisateur), rotation
  `(rotate (xyz 270 0 90))` nécessaire pour le redresser
- C1 (`A786.pretty`) : `composants-datasheets/datasheets/capacitors/A786MW477M1VLAV010.step`
  (modèle Mouser/SamacSys, téléchargé par l'utilisateur)

Alignement vérifié visuellement dans KiCad par l'utilisateur au fur et à
mesure — pas de rendu 3D possible côté agent, uniquement validation
syntaxique (`kicad-cli fp export svg`).

## 13. Secondaire UCC5304 + retour Vout isolé AMC0311S (2026-09-30)

Deux changements demandés par l'utilisateur, ajoutés par édition
chirurgicale de `isolation.kicad_sch` (suppression/ajout de blocs ciblés,
jamais de régénération — voir note ci-dessus) :

**1. ISO7710 (U4) + UCC27517 (U2) secondaires → UCC5304 (U6) seul.**
UCC5304 (`datasheets/isolation/ucc5304.pdf`, p.3 tbl Pin Functions, DWV-8) :
driver de grille isolé renforcé 4A source/6A sink, une seule puce fait ce
que faisaient les deux composants combinés (isolation + drive). Brochage :
IN(1)=PWM_SEC_IN, VCCI(2,3)=RAIL_3V3_PRI, GND(4)=GND, VSS(5,6)=VOUT_N,
OUT(7)=SEC_GATE_DRV (→ R12 → GATE_Q2, résistance de grille déjà posée par
l'utilisateur), VDD(8)=VBOOT. Empreinte
`Package_SO:SOIC-8_7.5x5.85mm_P1.27mm` (standard KiCad — comparaison
pastille-à-pastille contre le land pattern datasheet p.30 : 1,8×0,6mm,
pas 1,27mm, correspondance quasi-exacte, pas d'empreinte custom requise).

Le canal secondaire ne recevait déjà pas de signal EN isolé (IN+ de
l'ancien U2 était câblé sur VBOOT, toujours actif dès le bootstrap monté)
— remplacer par UCC5304 (une seule broche IN) ne perd donc aucune
fonction.

**Point ouvert (marge VDD)** : VBOOT ≈ Vout_min − Vf(D2) ≈ 6,3 − 0,3~0,5 ≈
5,8-6,0V au coin réel le plus bas (§3) — juste à la limite basse
recommandée de VDD (6V) de l'UCC5304, quoique nettement au-dessus de son
UVLO réel (5V typ, p.1/p.4). Marge plus courte que l'ancien UCC27517
(4,5V mini) — à surveiller au banc.

**2. Retour Vout isolé — AMC0311S (U7), nouveau, absent de la spec
initiale.** AMC0311S (`datasheets/isolation/amc0311s.pdf`, p.3 tbl 5-1,
DWV-8) : ampli isolé précision, gain fixe 1V/V, entrée linéaire 0-2,25V
(clipping doux à 2,56V, p.4 tbl 6.3). Reg3 (MCP1703, déjà en place pour
l'ancien ISO7710 secondaire) est **réutilisé**, pas orphelin : il
alimentait VCC2 de U4, alimente maintenant VDD1 de U7.

```
Côté secondaire (field, VOUT_N-référencé) :
  VDD1=RAIL_3V3_SEC (Reg3)   GND1=VOUT_N   SNSN=VOUT_N (« connect to GND1 »)
  INP=VOUT_SENSE (point milieu diviseur R13/R14)
Côté primaire (control, GND-référencé) :
  VDD2=RAIL_3V3_PRI   GND2=GND   REFIN=GND (« connect to GND2 if unused »)
  OUT=VOUT_FBACK_RAW (→ filtre R15/C24 → VOUT_FBACK, vers Cpu1)
```

**Diviseur R13/R14** (sonde VOUT_P/VOUT_N vers INP), + **C23 = 100pF**
en parallèle de R14 sur demande explicite de l'utilisateur (compense la
réponse HF du pont) :
```
R13 = 51k (haut)   R14 = 10k (bas)   ratio = 10/61 = 0,1639
Vout=13V (spec max)    → INP=2,13V   (< 2,25V linéaire, marge 0,12V)
Vout=12,6V (coin réel) → INP=2,07V
Vout=6,3V  (coin réel) → INP=1,03V
```

**Filtre RC de sortie** (R15=100Ω série, C24=1nF vers GND, sur demande de
l'utilisateur) : fc≈1,6MHz — valeurs par défaut, n'entament pas la bande
passante propre de l'AMC0311S (~120kHz typ), à revoir une fois la spec
d'entrée ADC du C2000 connue (point ouvert, §11).

**Découplage (règle utilisateur, 100nF/0805 par CI)**, appliquée à U6/U7
uniquement (pas de retrofit sur U1/U3/U5, décision explicite) :
C25 (RAIL_3V3_PRI-GND, U6 VCCI), C26 (VBOOT-VOUT_N, U6 VDD), C27
(RAIL_3V3_SEC-VOUT_N, U7 VDD1), C28 (RAIL_3V3_PRI-GND, U7 VDD2).

**3. Cpu1 (ex-J2, connecteur de commande vers le C2000 externe) agrandi de
4 à 16 broches** (8 signaux + 8 masses en alternance stricte 1:1) — reprend
le motif déjà en place sur `KICAD-C2000-devkit` (liaison shield↔puissance,
4 nappes 2×8). Meilleure intégrité de signal sur les fronts PWM isolés et
le retour analogique (masse dédiée adjacente à chaque signal plutôt
qu'une masse unique partagée) et marge pour signaux futurs :
```
1=PWM_PRI_IN 2=GND 3=EN_PRI_IN 4=GND 5=PWM_SEC_IN 6=GND
7=VOUT_FBACK 8=GND 9/11/13/15=réserve (no_connect) 10/12/14/16=GND
```
Cpu1 (ancienne version 4 broches) n'était en réalité **pas câblé** au
moment de sa découverte — déplacé/renommé depuis J2 sans que les
étiquettes suivent le déplacement. Aucune connectivité perdue en le
remplaçant par la version 16 broches.

Vérification : `kicad-cli sch erc` sur la hiérarchie complète après
édition — **0 erreur**, 4 avertissements (tous attendus : `lib_symbol_mismatch`
MSD1514 déjà documenté comme bénin, + `ground_pin_not_ground` sur U6 VSS×2
et U7 GND1 — même motif déjà accepté pour l'ancien U4, le secondaire
flottant est référencé à `VOUT_N` et non à un net nommé `GND` par
conception).

## 13bis. Retour sur UCC5304 — marge UVLO insuffisante pour un filament réglable (2026-09-30)

**UCC5304 abandonné côté secondaire, retour à ISO7710 (U4) + UCC27517
(U2)** comme avant §13. Cause : l'utilisateur veut pouvoir régler la
tension filament 5 à 10% en dessous du nominal 6,3V, donc supporter
Vout≈5,8V **en régime établi**, pas seulement en transitoire.

Seuils UVLO réels de l'UCC5304 (`datasheets/isolation/ucc5304.pdf`, p.8
tbl 6.9 Electrical Characteristics — pas la valeur unique simplifiée
« 5V UVLO » de la page de garde) :

| Seuil | Min | Typ | Max |
|---|---|---|---|
| VDD UVLO montée (démarrage) | 5,0V | 5,5V | 5,9V |
| VDD UVLO descente (reste actif) | 4,7V | 5,2V | 5,6V |

À Vout=5,8V : VBOOT ≈ 5,8 − Vf(D2) ≈ 5,4-5,5V (Vf BAT54 à faible courant,
§8) — **en dessous du seuil de démarrage typique (5,5V) et du seuil de
maintien pire-cas (5,6V)**. Risque réel de non-démarrage ou de décrochage
UVLO en régime établi, pas qu'une marge « recommandée » entamée comme au
coin 6,3V (§13). L'ancien UCC27517 (UVLO ≈4,2V typ, `carte-puissance/
ucc27517.yaml`) conserve une marge large jusqu'à 5,8V. **U7 (AMC0311S) et
le retour Vout isolé sont conservés inchangés** — ce point ne concernait
que le choix du driver secondaire.

**D2 : BAT54 (SOD-123, 2 broches) → BAT54C (SOT-23, Schottky double
cathode commune)**, décision utilisateur indépendante prise au même
moment : pin1(A)=VOUT_P, pin3(K commune)=VBOOT, pin2 (2e anode) en
réserve (`no_connect`). Objectif : grappiller de la marge sur Vf en
prévision d'un futur ajustement, la référence exacte reste à sourcer
(`composants-datasheets/data/carte-flyback/`, remplace `bat54.yaml` s'il
existait déjà une fiche pour l'ancien BAT54 — à vérifier).

Édition chirurgicale : retrait de U6/C25/C26 (+ leurs étiquettes, qui ne
sont PAS des enfants du bloc symbole dans ce format de fichier et doivent
être retirées séparément), repose de U4/U2 au brochage d'origine, D2
remplacé. `kicad-cli sch erc` : **0 erreur**, 3 avertissements — retour
exact à la même catégorie d'avertissements que la toute première version
du schéma (MSD1514 + GND2 de U4 + GND1 de U7, ce dernier n'existant pas
avant l'ajout du retour Vout).

## 14. Retours température primaire et courant primaire isolés, migration AMC0311S→AMC0311R (2026-10-02)

**Bug trouvé et corrigé — C20/C22 n'étaient pas les seuls.** En vérifiant
le câblage de U7 avant de le dupliquer pour un nouveau capteur, C18
(découplage côté `VDD1`/`GND1` de U7, censé être `RAIL_3V3_SEC`/`VOUT_N`
comme le reste du secondaire flottant) s'est révélé câblé
`RAIL_3V3_SEC`/**`GND`** — même défaut que C20/C22 (§ séance précédente,
pont AC vers le primaire sur un rail flottant). Corrigé : label `GND` du
côté concerné → `VOUT_N`.

**AMC0311S → AMC0311R (U7), et AMC0302R introduit (U9).** TI a réorganisé
cette famille d'amplis isolés en deux lignées : suffixe **R** = sortie
single-ended ratiométrique (calée sur `REFIN`, branchable directement sur
un ADC sans étage supplémentaire), suffixe **D** = sortie différentielle à
gain fixe (nécessite soit un réseau résistif précis soit un ampli-op
tampon pour respecter l'impédance source voulue par l'ADC SAR du C2000).
U7 est renommé AMC0311S→**AMC0311R** (même brochage VDD1/INP/SNSN/GND1 —
GND2/REFIN/OUT/VDD2, fiche `datasheets/isolation/amc0311r.pdf`). Nouveau
boîtier : **DWV** (SOIC-8 large, 5,85×11,5mm, isolation renforcée 5kVrms)
— aucune empreinte KiCad standard ne couvre cette taille (le plus grand
SOIC-8 bundled plafonne à 7,5×5,85mm), empreinte custom créée :
`lib_fp/SOIC_DWV.pretty/SOIC-8_DWV_5.85x11.5mm_P1.27mm.kicad_mod`, cotes
du land pattern fournies par l'utilisateur (crop datasheet, 2026-10-02) :
8 pastilles 1,8×0,6mm, pas 1,27mm, entraxe gauche-droite 10,9mm (9,1mm de
creepage nominal entre les deux groupes — c'est cet écart qui impose le
boîtier large). Modèle 3D `DWV0008A.stp` fourni par l'utilisateur, attaché
en transformation identité (offset/rotate à affiner dans KiCad comme pour
les autres empreintes custom).

**U8 — AMC0311R, retour température primaire isolé** (nouveau, absent de
la spec initiale). Surveille la température MOSFET/transformateur côté
primaire. Diviseur NTC (TH1, 10k/B=4000, 0805) + R16 (680Ω) :
`RAIL_3V3_PRI`→TH1→nœud→R16→`GND`, nœud sur `INP` ; `SNSN`=`GND`. NTC en
haut (sortie croissante avec la température, meilleure résolution côté
chaud) : ≈0,21V à 25°C, ≈2,19V à 125°C — dans la plage linéaire 0-2,25V de
l'AMC0311R, marge avant l'écrêtage souple à 2,56V. C29 (100pF) en
compensation `INP`-`SNSN`, comme sur U7. Sortie filtrée R17(100Ω)/C30(1nF)
→ `TEMP_PRI_FBACK`. Découplage C25/C26 (100nF).

**U9 — AMC0302R, retour courant primaire isolé** (nouveau, protection
MOSFET primaire). Shunt bas côté (R19, 1210, valeur provisoire 7,5mΩ — à
sourcer en passe dédiée) inséré en série entre la source de Q1 et `GND`
dans `flyback.kicad_sch`, lu en différentiel par U9 : `INP`=`ISENSE_P`
(côté source Q1), `INN`=`GND` (un shunt 2 bornes n'a pas de masse de sens
séparée — même nœud physique que le retour de courant). AMC0302R choisi
plutôt que la famille ±250mV (AMC0300R/AMC0202R) : avec Ipk=6,55A/
Irms=3,37A (coin 6,3V/3A, §3), un shunt ±50mV (≈7,5mΩ) dissipe ≈0,09W en
régime établi contre ≈0,43W pour un shunt ±250mV (≈38mΩ) — marge plus
confortable sur un boîtier 1210. Sortie filtrée R18(100Ω)/C33(1nF) →
`ISENSE_PRI_FBACK`. Découplage C31/C32 (100nF).

**Les deux nouveaux isolateurs étaient d'abord câblés côté contrôle sur
`RAIL_3V3_PRI`/`GND`** (comme U7 à l'époque) — migré vers `GND_CTRL`/
`3V3_CTRL` dans la même session, voir §15.

Édition chirurgicale sur `isolation.kicad_sch` et `flyback.kicad_sch`
(insertion de R19 en série sur une broche déjà câblée de Q1). Bug
d'outillage rencontré et corrigé en cours de route : une suppression de
fil par recherche de chaîne à indentation fixe a coupé un bloc
multi-lignes au mauvais endroit (le texte `'\t)\n'` matchait aussi
l'intérieur de `'\t\t)\n'`), laissant un fragment orphelin qui décalait
tous les niveaux de parenthèses du fichier d'un cran — détecté par
comparaison du nombre de `(` et de `)` sur le fichier entier (3482 contre
3483), corrigé en retirant le fragment exact. Deuxième bug trouvé via le
même type de symptôme : le cache `(lib_symbols ...)` embarqué dans
`isolation.kicad_sch` n'avait jamais été mis à jour (resté sur
`AMC0311S`, jamais eu `AMC0302R` ni `Device:Thermistor_NTC`) —
`kicad-cli` résout les pins depuis CE cache, pas depuis la bibliothèque
externe ; symptôme : tous les pins d'un symbole renvoyés en
`pintype "unspecified"` sur un faux net unique, ce qui fait remonter en
ERC des `pin_not_connected`/`label_dangling` épars et trompeurs. Les deux
leçons sont documentées en détail dans la mémoire de session. `kicad-cli
sch erc` final : **0 erreur**, warnings restants = avertissements attendus
déjà présents (GND2/GND1 sur net flottant `VOUT_N`, cache MSD1514
préexistant) + désalignements de grille cosmétiques sur les nouveaux
composants (replacement manuel prévu par l'utilisateur, comme pour tous
les ajouts précédents sur ces feuilles).

## 15. Isolation réelle du C2000 — GND_CTRL/3V3_CTRL, connecteur scindé en 2 (2026-10-02)

Mise en œuvre du point ouvert du §14 : jusqu'ici U3 (et dans une moindre
mesure U4/U5/U7/U8/U9 côté contrôle) partageaient `RAIL_3V3_PRI`/`GND`
des deux côtés de leur barrière d'isolation — la puce isolante existait,
mais sans séparation galvanique réelle vis-à-vis du C2000 externe, les
deux « côtés » étant en fait le même rail/masse générés localement sur
cette carte.

**Câblage migré vers `3V3_CTRL`/`GND_CTRL`** (alimentation/masse
réellement importées depuis la carte C2000, sans lien cuivre avec
`RAIL_3V3_PRI`/`GND`) :

| Composant | Broches migrées | Broches inchangées |
|---|---|---|
| U3 (ISO7710, PWM primaire) | VCC1(1,3), GND1(4) | VCC2(8)/GND2(5) → primaire local (vers U1) |
| U4 (ISO7710, PWM secondaire) | VCC1(1,3), GND1(4) | VCC2(8)/GND2(5) → `RAIL_3V3_SEC`/`VOUT_N`, secondaire flottant |
| U5 (DPC817, EN) | pin2 (cathode) | pins3/4 (sortie) → primaire local |
| U7 (AMC0311R, retour Vout) | VDD2(8)/GND2(5)/REFIN(6) | VDD1/GND1/SNSN → secondaire flottant |
| U8 (AMC0311R, retour température) | VDD2(8)/GND2(5)/REFIN(6) | VDD1/GND1/SNSN → primaire local (thermistance) |
| U9 (AMC0302R, retour courant) | VDD2(8)/GND2(5)/REFIN(6) | VDD1/GND1/INN → primaire local (shunt) |

Chaque composant migré garde son découplage 100nF propre, lui aussi
basculé sur `3V3_CTRL`/`GND_CTRL` (C15 pour U3, C17 pour U4, C28 pour U7,
C26 pour U8, C32 pour U9).

**Connecteur Cpu1 (8 broches, un seul) scindé en deux nappes 2x4**,
séparées par sens de signal :

```
CpuOut (sorties C2000 -> carte)      CpuIn (entrées C2000 / ADC)
1 = 3V3_CTRL                         1 = 3V3_CTRL
2 = GND_CTRL                         2 = GND_CTRL
3 = PWM_PRI_IN                       3 = VOUT_FBACK
4 = GND_CTRL                         4 = GND_CTRL
5 = EN_PRI_IN                        5 = TEMP_PRI_FBACK
6 = GND_CTRL                         6 = GND_CTRL
7 = PWM_SEC_IN                       7 = ISENSE_PRI_FBACK
8 = GND_CTRL                         8 = GND_CTRL
```

Les 4 broches de marge prévues sur CpuIn (§13) ont été consommées par
les deux nouveaux retours température/courant — plus de marge disponible
sur ce connecteur pour un futur ajout, à rouvrir si besoin.

**`PWR_FLAG` ajoutés sur `3V3_CTRL`/`GND_CTRL`** (sur CpuOut) : ces rails
sont importés depuis la carte C2000, invisibles pour l'ERC de cette
feuille — même convention déjà utilisée dans `alim.kicad_sch` pour
`VIN`/`GND`/`VBOOT`/`VOUT_N`, sans quoi ERC lève `power_pin_not_driven`
sur chaque pin `power_in` de ce nouveau rail.

Édition chirurgicale (22 renommages de label ciblés par coordonnée exacte
— jamais de remplacement global `RAIL_3V3_PRI`→`3V3_CTRL`, qui aurait
cassé le primaire — + suppression de Cpu1 et ses 8 étiquettes + ajout de
2 connecteurs + 2 PWR_FLAG). Même bug de cache `lib_symbols` que le §14,
cette fois sur `power:PWR_FLAG` (jamais utilisé dans cette feuille avant
ces 2 flags) — diagnostiqué et corrigé par la même méthode. `kicad-cli
sch erc` final : **0 erreur**, 37 avertissements (même famille que §14 :
désalignements de grille cosmétiques sur les nouveaux objets +
avertissements `GND`-flottant déjà acceptés).

**Reste à faire côté utilisateur** : replacement de CpuOut/CpuIn et de
tous les composants migrés dans KiCad (positions provisoires côté
script), mise à jour du PCB (F8), et vérification visuelle que le
système C2000 externe n'a pas déjà une masse reliée à celle de cette
carte par un autre chemin (boîtier, câble blindé) — auquel cas la
séparation serait refaite ailleurs sans que le schéma le montre.

## 16. Nouvelle feuille « Polarisation » — pilotage actif de HV_BIAS depuis une source 80V (2026-10-02)

Besoin exprimé : piloter depuis le C2000 la tension du point milieu du
pont symétrique existant (R9/R10, 2×100kΩ entre `VOUT_P` et `VOUT_N`,
`flyback.kicad_sch`) — ce point (`HV_BIAS`, déjà posé par l'utilisateur
avec un connecteur-témoin `Bias1`) fixe de combien le secondaire flottant
est élevé au-dessus du primaire. Jusqu'ici réglé passivement ; nouveau
besoin : le rendre réglable depuis une alimentation externe dédiée fixe
80V (`J1`/`HV80_IN`), pilotée/lue par le C2000. (Première itération
envisagée à 400V avec une chaîne de 4 résistances en série pour la tenue
en tension ; simplifiée à 80V fixe — un seul 0805 suffit, cf. schéma
réel.)

**Nouvelle feuille `polarisation.kicad_sch`**, raccrochée à la racine
(page 5), régénérée en respectant les conventions du projet : étiquettes
globales uniquement (aucun segment de fil explicite), tous les
composants alignés sur la grille 1,27mm. Chaîne complète :

**Source de courant régulée** (`HV80_IN`→`HV_BIAS`, remplace un simple
pont résistif après calcul du courant de fuite probable) : Q3 (BSS127I,
élément de puissance) + Q4 (MMBT2222, boucle de régulation) + R25 (2kΩ,
fixe le point de régulation à I=Vbe/R25) + R26 (résistance unique,
polarisation grille Q3 depuis `HV80_IN` — valeur corrigée par simulation,
voir §16bis). Pourquoi un courant régulé plutôt qu'un pont résistif
classique : le courant de fuite chauffage-cathode des tubes (~1µA/tube
×10 tubes ≈10µA max, à confirmer sur le datasheet du tube réel) doit
rester négligeable devant le courant de polarisation — large marge dans
tous les cas, la boucle logicielle absorbe le reste.

**Protection `HV_BIAS`** : D3 (TVS SMCJ100A, même famille que D1)
clampe à ~100V si Q5 se bloque ; R21 (1MΩ) tire la grille de Q5 vers
`RAIL_3V3_PRI`, donc une perte de commande sature Q5 (HV_BIAS→~0V,
sens sûr) plutôt que de le bloquer.

**Commande grille Q5 (BSS127I, résistance variable 0-180kΩ)** : PWM du
C2000 → U10 (ISO7710, traverse `GND_CTRL`↔`GND` comme U3/U4) → filtre
R20(10k)/C36(100nF) → grille Q5. Logic-level (Vth max 2,6V) choisi
spécifiquement pour ce rôle — un MOSFET de puissance standard (Vth
3-4V) ne garantirait pas de conduire avec seulement 3,3V de commande.
Plage réelle de `HV_BIAS` atteignable : voir §16bis (bornée par la
source de courant, pas par Q5).

**Retour mesure `BIAS_FBACK`** : diviseur R22(470k)/R23(10k) (ratio
calé pour amener 100V→2,08V, sous le plafond 2,25V de l'AMC0311R) + C40
(100pF comp.) → U11 (AMC0311R, 4e instance, même famille que
U7/U8/U9) → filtre R24(100Ω)/C41(1nF) → `BIAS_FBACK`.

**Connecteurs C2000 agrandis 2x04→2x08 (16 broches)**, décision de
l'utilisateur pour garder de la marge et rester standard avec
d'autres cartes (shield, devkits) : `CpuOut`/`CpuIn` recréés en
`Connector_Generic:Conn_01x16` / `PinHeader_2x08_P2.54mm_Vertical`,
8 signaux existants conservés + `PWM_BIAS_IN`/`BIAS_FBACK` nouveaux +
6 broches de marge (3 par connecteur) pour de futurs ajouts. Nouveau
connecteur dédié `J1` (`HV80_IN`) pour l'alimentation 80V externe,
avec son propre `PWR_FLAG`.

**Composants ajoutés à `lib/custom_parts.kicad_sym`** : BSS127I et
MMBT2222, construits en autonome (pas de mécanisme `extends` de la
bibliothèque standard KiCad — `Transistor_FET:BSS127S` hérite de
`Q_NMOS_GSD`, ambigu à mettre en cache correctement dans une feuille,
cf. mémoire de session) avec le même brochage que les symboles standard
KiCad (G/S/D ou B/E/C aux mêmes coordonnées), mais pointant vers la
datasheet Infineon réellement sourcée plutôt que la référence
générique Diodes Inc. du symbole KiCad.

Deux bugs trouvés et corrigés en cours de route (détaillés en mémoire
de session) : (1) `Device:D_TVS` a des broches horizontales
`(-3.81,0)/(3.81,0)`, pas verticales comme `Device:R`/`Device:C` — un
générateur de coordonnées validé sur R/C donnait des broches "non
connectées" en ERC pour D3 tant que ce n'était pas corrigé ; (2) le
cache `lib_symbols` de `isolation.kicad_sch` n'avait pas
`Connector_Generic:Conn_01x16` (jamais utilisé dans cette feuille avant
l'agrandissement des connecteurs C2000) — même symptôme et même
diagnostic que pour `AMC0302R`/`power:PWR_FLAG` au §15.

`kicad-cli sch erc` sur le projet complet (4 feuilles) : **0 erreur
inattendue** — seules les 6 broches de marge volontairement non
connectées (NC) sur les connecteurs 16 broches remontent en erreur
(attendu pour des broches de réserve), plus les avertissements déjà
documentés (grille cosmétique sur les nouveaux composants, `GND`
flottant sur `VOUT_N`, cache MSD1514 préexistant).

**Reste à sourcer/vérifier** : courant de fuite réel du tube utilisé
(datasheet constructeur, remplace l'hypothèse 1µA/tube), valeur
définitive de R25 (dépend de la vraie plage de conduction du BSS127I
mesurée au banc, pas juste du Vbe), et le repositionnement de tous les
nouveaux composants dans KiCad (placés par script à des coordonnées
provisoires, comme d'habitude sur ces feuilles).

## 16bis. Simulation SPICE de la source de courant — R26 corrigé de 2M7 à 75k (2026-10-03)

Avant de sourcer les composants, simulation du sous-circuit Q3/Q4/R25/R26
sous ngspice (binaire console officiel, hors KiCad qui n'embarque
`ngspice.dll` que pour son usage interne), avec les modèles SPICE réels
du fabricant Diodes Inc. (second-source de la famille BSS127 et du
MMBT2222A — pas l'Infineon BSS127I réellement sourcé, donc résultat
indicatif sur la valeur exacte, fiable sur l'allure du comportement ; à
confirmer au banc avec la pièce réelle).

**Erreur de topologie trouvée** : l'hypothèse de conception initiale
(« R26 ne fournit qu'un léger courant de polarisation de grille, le
canal D-S de Q3 porte l'essentiel du courant régulé ») est fausse. La
simulation montre que le canal de Q3 reste quasi inerte (<1µA) sur toute
la plage : la contre-réaction via Q4 maintient Vgs(Q3) à peine au-dessus
du seuil, donc la quasi-totalité du courant imposé par R26 est détournée
par Q4 (collecteur→émetteur) vers R25, pas par le canal de Q3. Consé-
quence directe : **c'est R26 qui fixe le courant disponible**
(I ≈ (80V − HV_BIAS − ~3V de marge Vgs+Vbe)/R26), pas R25/Vbe seuls. Le
montage se comporte donc, sur toute sa plage utile, plus comme une
résistance (décroissance quasi linéaire du courant avec `HV_BIAS`) que
comme une vraie source de courant plate.

Avec la valeur d'origine (2M7, dimensionnée pour ~300µA sous l'hypothèse
fausse ci-dessus), le courant réellement disponible n'atteignait que
20-30µA en simulation — largement insuffisant.

**Courbe de compliance mesurée** (balayage de `HV_BIAS` forcé de 0 à
80V, modèle Vth=2,0V représentatif de l'Infineon BSS127I) pour R26=75k,
valeur retenue :

| HV_BIAS | Courant disponible |
|---|---|
| 0V | 1,01mA |
| 40V | 0,49mA |
| 60V | 0,23mA |
| 75V | 32µA |
| 78V | ≈0 |

Courant quasi nul au-delà de ~78V (marge de tension de la boucle
Q3/Q4 — Vgs(Q3)+Vbe(Q4)+chute R25, ~3V — épuisée face au rail fixe
80V) ; décision explicite de l'utilisateur d'accepter ce comportement
(1mA en bas de plage, encore quelques dizaines de µA à 75V) plutôt que
de viser une vraie source de courant plate sur toute la plage.

**R26 : 2M7 → 75k** (valeur standard E24) appliqué dans
`polarisation.kicad_sch`. Dissipation vérifiée au pire point (HV_BIAS=0V,
~75,3V aux bornes de R26, 1,01mA) : ~76mW, sous les 125mW d'un 0805 —
pas de changement de boîtier nécessaire. `kicad-cli sch erc` re-vérifié
sur le projet complet : aucune violation nouvelle (même base qu'au §16).

## 17. Redressement synchrone secondaire réel — UCC24612 (U12) remplace U2/U4, clamp D4 ajouté (2026-10-04)

Suite de `doc/sim-vs-mesure.md` §7/§7bis : la cible réelle (18,9W) a été
simulée avec un proxy de redressement synchrone (grille idéale) avant
d'intégrer le vrai composant. Verdict : tenable **à condition** d'ajouter
un clamp secondaire sur Q2 (absent jusqu'ici — point ouvert du §11
ci-dessus, passé de souhaitable à bloquant à cette puissance). Les deux
changements ci-dessous découlent de ce verdict chiffré, pas d'un choix a
priori.

**U2 (UCC27517) + U4 (ISO7710) retirés, remplacés par U12 (UCC24612).**
Cause : le canal secondaire était piloté « à l'aveugle » — PWM_SEC_IN
depuis le C2000, timing fixé par le firmware, aucun retour sur le vrai
Vds de Q2. L'UCC24612 élimine ce problème par construction (détection
Vds, diode emulation) : plus besoin d'isolateur ni de canal PWM dédié
pour ce rôle, net moins de composants (2 CI retirés, 1 plus petit
ajouté). Config **low-side** (source de Q2 déjà côté masse secondaire) :

```
VG(1)  -> R12 (déjà posée, inchangée) -> GATE_Q2
VS(2)  -> VOUT_N (même label que l'ancien GND de U2, position reprise)
REG(3) -> REG_SR -> C42 (2,2µF, obligatoire : courant de grille moyen
          Qg×fsw ≈ 10-13mA > seuil 5mA de la datasheet §9)
VDD(4) -> VOUT_P directement (recommandation datasheet §9 pour le
          low-side, Vout 5,8-13V dans la plage admise 4,5-28V — pas
          besoin d'enroulement auxiliaire ni de R-C-D, réservés au
          high-side) + C43 (100nF, bypass HF local, en plus du banc Cout)
VD(5)  -> SW_SEC (Kelvin direct vers le drain de Q2, piste dédiée hors
          chemin de puissance par construction — même nœud que T1 pin2
          et D4 cathode)
```

Nouveau symbole `custom_parts:UCC24612` (SOT23-5, même boîtier que
l'ancien UCC27517 — zéro changement d'empreinte), ajouté à
`lib/custom_parts.kicad_sym` sur le même modèle que UCC27517/ISO7710.
U12 reprend la position exacte de l'ancien U2 ; ses pins VG/VS tombent
sur les mêmes coordonnées que les anciens OUT/GND de U2, donc le fil
existant vers R12 et le label VOUT_N n'ont pas eu besoin d'être retouchés
— seuls VDD/VD/REG (anciens VDD/IN+/IN- de U2, sur VBOOT) ont été
rebranchés.

**D4 (SMCJ54A) ajouté** en clamp secondaire, cathode=SW_SEC (drain Q2),
anode=VOUT_N — même construction/orientation que D1. Choix chiffré en
détail dans `doc/sim-vs-mesure.md` §7bis : clampe Vds_Q2 à ~61-65V
(marge ×1,5 vs les 100V du MOSFET) pour 0,03-0,76W de dissipation (marge
×7 vs son propre P_av=5W). Le SMCJ43A (même réf. que D1) a aussi été
testé et tient les deux contraintes, mais coûte jusqu'à 2 points de
rendement système en plus (le clamp n'absorbe pas qu'une perte locale —
le couplage K1 L1 L2 relie les deux résonances, écrêter plus bas côté
secondaire fait tirer davantage sur Vin pour un Pout quasi identique) —
le SMCJ54A est donc retenu malgré la référence BOM supplémentaire.

**VBOOT/D2(BAT54C)/C8(Cboot)/C20/C22 retirés par l'utilisateur**
(édition GUI directe, même session) — vestigiaux depuis que VDD de
l'UCC24612 va directement sur VOUT_P, comme déjà noté ci-dessus. Mais
**ce nettoyage a cassé l'alimentation de Reg3** (MCP1703, LDO 3,3V
secondaire) sans que son rôle disparaisse : Reg3 reste nécessaire pour
VDD1 de U7 (AMC0311R, retour Vout isolé). Deux incidents trouvés et
corrigés dans la foulée (ERC + vérification croisée, pas juste visuel) :

1. Reg3 supprimé entièrement (pas juste rebranché) → son VI n'était plus
   alimenté. **Recréé** dans `flyback.kicad_sch`, VI câblé directement
   sur VOUT_P (au lieu de l'ancien VBOOT/D2) — Vin_max MCP1703=16V vs
   VOUT_P max=13V, marge ×1,23 (`mcp1703.yaml`), largement suffisant
   sans bootstrap.
2. **Plus grave** : en attendant, VDD1 de U7 avait été rebranché
   directement sur VOUT_P (13V) — or VDD1 de l'AMC0311R a un maximum
   absolu de **6,5V** (`amc0311r.pdf` §6.1) : ça aurait détruit le
   composant au premier démarrage à Vout élevé. Rebranché sur
   `RAIL_3V3_SEC` (sortie régulée de Reg3) à la place.

Les deux corrections ont été trouvées en recroisant `kicad-cli sch export
netlist` après l'édition GUI de l'utilisateur, pas par relecture visuelle
— la marge de l'AMC0311R en particulier n'était pas quelque chose
d'évident à repérer à l'œil sur le schéma.

**PWR_FLAG ajouté sur VOUT_P** (`alim.kicad_sch`, même rangée que les
PWR_FLAG VIN/GND/VOUT_N déjà en place) — nécessaire car VDD de U12 est le
premier pin de type *power input* jamais posé sur ce net (jusqu'ici
VOUT_P n'était touché que par des pins *passive*, qui n'ont pas besoin
d'un flag). Sans lui, ERC lève `power_pin_not_driven` sur VDD.

**Vérification.** `kicad-cli sch erc` sur le projet complet, état final
(après nettoyage utilisateur + corrections Reg3/U7 ci-dessus) : 213
violations (223 avant ce §17), **7 erreurs — même famille déjà connue et
acceptée** (broches de réserve CpuOut/CpuIn non connectées, §16 ; le
7e, `CpuOut1` pin 7 = ancien `PWM_SEC_IN`, rejoint cette catégorie
puisque l'UCC24612 n'a plus besoin de ce signal firmware). Aucune
violation `power_pin_not_driven` ni autre anomalie électrique restante.

**Marge UVLO à surveiller au banc (pas un point bloquant, juste plus
tendu que souhaité)** : à Vout_min=5,8V (filament réglé bas, §13bis),
VDD=VOUT_P=5,8V directement. Seuil UVLO réel de l'UCC24612
(`ucc24612.pdf` tbl 6.5, mesuré sur REG) : VREG_ON max=4,87V, dropout
max=0,45V à VDD=5V → VDD nécessaire ≈5,32V pire cas. Marge ≈0,48V —
positive (contrairement au rejet de l'UCC5304 en §13bis qui avait une
marge négative dans ce même scénario), mais plus courte que souhaité ;
à vérifier en charge réelle avant de considérer le point tranché.

**Reste à faire côté utilisateur** : replacement de U12/C42/C43/D4/Reg3
dans KiCad (positions provisoires côté script, mêmes désalignements de
grille cosmétiques que chaque ajout précédent) et mise à jour du PCB
(F8) — le nettoyage VBOOT/D2/C8/C20/C22 est fait.

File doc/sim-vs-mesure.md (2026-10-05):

# Validation — calcul, simulation, mesure

Étage flyback de `alim-flyback-filament`, redressement passif par la
diode de corps de Q2 (étape de validation avant le contrôleur de
redressement synchrone UCC24612).

> **État** : simulation étapes 1-4 faite avec les modèles réels
> (IPD050N10N5 Infineon, clamp D1 SMCJ43A). **Prototype non mesuré.** Les
> colonnes « Mesure » restent vides tant qu'elles n'ont pas été remplies
> au banc — jamais complétées par des valeurs simulées.

---

## 1. Conditions communes

| Paramètre | Valeur |
| --- | --- |
| f_sw | 200 kHz |
| Couplage | Coilcraft MSD1514-103ME, 1:1, 10µH, k=0,99 (datasheet) |
| MOSFET Q1/Q2 | IPD050N10N5 réel (Infineon, sous-circuit SPICE officiel OptiMOS5, `simulation/models/IPD050N10N5.lib`) |
| Redresseur | Diode de corps de Q2 (gate à 0V) — pas de Schottky discret dans le vrai chemin de puissance |
| Clamp primaire | D1 = SMCJ43A réel (Vbr=47,8V@1mA, Vc=69,4V@21,7A, `smcj43a.yaml`) |
| Clamp secondaire | **aucun modélisé** — voir §2, c'est la limite la plus importante de cette passe |
| Puissance visée  | 10W (6V et 12V), + un point à charge légère (~1W, mêmes duty cycle/Rload trouvés par itération) |
| Charge | Rload = Vout_cible² / Pout_cible |

## 2. Résultats (étapes 1-4)

| Point | Vin | D | Vout | Pout | η | Mode | Ipk pri | Irms pri | Vds Q1 max | Vds Q2 max |
|---|---|---|---|---|---|---|---|---|---|---|
| 11V→6V  | 11V | 38,3% | 5,96V | 9,88W | 85,0% | **CCM** | 4,13A | 1,85A | 49,8V | 57,4V |
| 11V→12V | 11V | 53,6% | 11,98V | 9,96W | 90,2% | **CCM** | 3,41A | 1,63A | 49,4V | 74,4V |
| 20V→6V  | 20V | 25,0% | 5,96V | 9,87W | 84,9% | **CCM** | 4,26A | 1,38A | 49,6V | 88,5V |
| 20V→12V | 20V | 30,2% | 11,90V | 9,84W | 90,9% | DCM | 3,75A | 1,20A | 49,4V | 75,7V |
| 25V→6V  | 25V | 21,1% | 6,00V | 10,00W | 84,1% | **CCM** | 4,62A | 1,30A | 50,7V | **106,7V** ⚠ |
| 25V→12V | 25V | 26,3% | 12,05V | 10,08W | 89,3% | DCM | 3,97A | 1,19A | 48,8V | **106,8V** ⚠ |
| 20V→6V, charge légère (~1W) | 20V | 11,3% | 6,13V | 1,04W | 81,0% | CCM (limite) | 1,80A | 0,37A | 34,9V | 53,0V |

CSV complet (avec le détail des pertes par poste) : `simulation/results/envelope.csv`.
Figure : `simulation/plots/envelope_eta_vds.png`.

**Mode de conduction déterminé sur la forme d'onde** (I(L2) juste avant le
rallumage de Q1, comparé au pic de courant primaire — pas supposé) : la
majorité des points réels sont **CCM**, pas DCM comme une première analyse
rapide l'avait suggéré à tort pour certains points. Seuls 20V→12V et
25V→12V ressortent DCM, et le point à charge légère est à la limite
(5,6% du pic, à retraiter avec plus de marge sur les seuils si on veut
trancher plus finement).

### ⚠ Constat le plus important de cette passe

**Vds_Q2 dépasse 100V (la tenue de l'IPD050N10N5) à Vin≥23V environ**,
côté secondaire, pendant la résonance qui suit le pic de conduction — sans
qu'aucun clamp secondaire ne soit modélisé (seul D1 côté primaire
existe). Vin_max de la spec est 25V (`00-intention-conception.md`) : les
points 25V→6V et 25V→12V simulent 106,7V et 106,8V, **au-delà de la
tenue en tension du composant réellement sourcé**. À traiter avant
d'aller plus loin : soit un clamp secondaire dédié, soit revérifier si le
réseau Lmesh_sec/Cinter ESTIMÉ (non sourcé, voir §3) exagère la résonance,
soit réduire Vin_max d'usage réel.

### Pertes — total fiable (Pin−Pout), décomposition non publiée

Pour chaque point, la somme des postes (Q1 total non séparé, diode de
corps Q2 totale non séparée, DCR primaire/secondaire, shunt, ESR Cout)
**ne retombe pas** sur Pin−Pout à ±5% (écart résiduel ~8-12% de Pin−Pout
selon le point, contre plusieurs dizaines de % avec l'ancien modèle de
substitution — nettement amélioré mais pas encore résolu). Conformément
à la règle de travail : **Pin−Pout fait foi comme perte totale**, la
décomposition Q1/Q2 n'est **pas** séparée en conduction/commutation/Coss
dans cette passe (reste à faire si besoin, étape 3 du plan complet).

## 3. Paramètres ESTIMÉS (non sourcés — à ne jamais traiter comme mesurés)

| Paramètre | Valeur utilisée | Pourquoi ESTIMÉ |
|---|---|---|
| `Lmesh_pri`, `Lmesh_sec` (inductances de maille primaire/secondaire) | ~0 (placeholder numérique, 1pH) dans cette passe | Aucune mesure de routage disponible avant le PCB réel. Le plan prévoit un balayage 0/nominal/2× — pas encore fait. |
| `Cinter_ESTIME` (capacité inter-enroulements) | 0 (composant présent dans le générateur, pas instancié dans cette passe) | Non publiée par Coilcraft pour le MSD1514-103ME. Sert à l'étape 6 (bruit de mode commun), hors scope ici. |
| Perte cœur transformateur (calculateur Coilcraft) | **pas recalculée** pour ces points | Les 282mW/291mW obtenus précédemment correspondent aux anciens points (modèle MOSFET de substitution, pas de clamp réel) — courants différents maintenant, à redemander à l'utilisateur sur les nouveaux Ipk/Irms de ce tableau si on veut un chiffre à jour. |

## 4. Protocole de mesure

À remplir avant la séance de banc.

| Élément | Choix |
| --- | --- |
| Alimentation | |
| Charge | (électronique / résistive — préciser) |
| Oscilloscope | modèle, bande passante, limitation BW |
| Sonde de tension | rapport, masse courte (ressort) oui/non |
| Mesure de courant  | sonde, ou shunt R19 + sonde différentielle |
| Mesure de Vout | multimètre, au plus près de Cout |
| Température | ambiante, et des composants après 10 min  |

Données brutes : `mesures/` — exports CSV de l'oscilloscope, un fichier
par capture, nommé `AAAAMMJJ_point_grandeur.csv`.

## 5. Comparaison des formes d'onde

Pour chaque point : la courbe simulée et la mesure superposées sur le
même graphique, depuis les CSV.

- [ ] Courant primaire I(L1)
- [ ] Courant secondaire I(L2) — fenêtre de conduction utile, mode CCM/DCM
- [ ] Tension drain Q1 — amplitude et amortissement de la résonance
- [ ] **Tension drain Q2 — vérifier en priorité le dépassement 100V prédit à Vin≥23V**
- [ ] Ondulation de Vout

## 2bis. Modèle simplifié (Schottky générique) — comparaison et perte clamp D1

Le modèle de redressement par diode de corps du vrai IPD050N10N5 (§2) est
fidèle mais lent (35-90s/point, convergence parfois capricieuse). Sur
demande explicite (comparer vite, et surtout **chiffrer la perte dans le
clamp D1** qui sera de toute façon présent quel que soit le choix de
redressement) : Q1 et D1 restent réels, le redressement secondaire est
remplacé par une Schottky générique simple (`.model D(IS=100n N=1
RS=5m)`, pas un composant réellement sourcé — juste un modèle rapide et
robuste pour ce comparatif).

| Point | η (diode de corps) | η (Schottky) | **Perte D1 (clamp)** |
|---|---|---|---|
| 11V→6V  | 85,0% | 88,0% | 336mW |
| 11V→12V | 90,2% | 91,5% | 327mW |
| 20V→6V  | 84,9% | 87,5% | 459mW |
| 20V→12V | 90,9% | 91,2% | 406mW |
| 25V→6V  | 84,1% | 86,5% | 616mW |
| 25V→12V | 89,3% | 87,9% | **891mW** |
| 20V→6V, charge légère | 81,0% | 85,8% | 0,8mW (négligeable) |

CSV : `simulation/results/envelope_schottky.csv`. Figure :
`simulation/plots/compare_real_vs_schottky.png`.

**Sur la perte clamp D1** : substantielle et monte avec Vin (jusqu'à
891mW à 25V/12V) — confirme que c'était une inquiétude fondée. Reste
large marge face à la tenue thermique du composant (P_av=5W max,
`smcj43a.yaml`) : marge ×5,6 au pire point. Pas un problème de
dimensionnement du composant, mais un vrai poste de rendement à ne pas
négliger dans le bilan global.

**Écart de rendement entre les deux modèles** : 1,5 à 3,5 points
d'efficacité selon le point (le Schottky simplifié est systématiquement
plus optimiste, sauf à 25V→12V où c'est l'inverse — à élucider, voir §6).
Cohérent avec l'attente : le modèle simplifié donne un ordre de grandeur
rapide, pas un chiffre de conception final — pour ça il faut soit le
modèle réel (lent), soit la mesure au banc.

**Vds_Q2 bien plus faible avec le modèle Schottky** (37-50V typiquement,
contre jusqu'à 106,8V avec le modèle réel, §2) — **ne pas conclure que le
dépassement 100V a disparu** : c'est le modèle simplifié qui ne reproduit
pas la résonance non-linéaire réelle du MOSFET. Le constat du §2 (Vds_Q2>100V à
Vin≥23V) reste la référence tant qu'il n'est pas infirmé par une mesure.

## 6. Inexpliqué / à vérifier

- Décomposition des pertes Q1/Q2 par poste (conduction/commutation/Coss)
  ne boucle pas avec Pin−Pout à ±5% — méthode de mesure à revoir (étape 3
  non terminée).
- Le point à charge légère (20V→6V, ~1W) est classé CCM à la limite
  (5,6% du pic de courant) — borderline, pas une conclusion ferme.
- Dépassement Vds_Q2 100V à Vin≥23V : pas encore confronté à une mesure
  réelle, ni revérifié avec un vrai modèle de Lmesh/Cinter (actuellement
  quasi nuls, donc la résonance simulée est probablement **optimiste** par
  rapport au PCB réel — l'écart pourrait être pire en vrai, pas meilleur).
- Point 20V→12V avec le modèle Schottky : Vout=10,84V, nettement sous la
  cible et sous le résultat du modèle réel (11,90V) au même D/Rload —
  seul point où le modèle simplifié donne un résultat moins favorable que
  le modèle réel (tous les autres vont dans l'autre sens). Pas élucidé,
  à revérifier avant de faire confiance à ce point précis.
- Convergence SPICE intermittente sur certains points (le même point peut
  échouer à une relance et réussir à la suivante) — pas bloquant
  (nouvelle tentative suffit) mais pas expliqué.

## 7. Passage à 18,9W (cible spec réelle) + redressement synchrone idéal (proxy UCC24612)

`00-intention-conception.md` §2 fixe la cible réelle de la carte à
**18,9W** (10 filaments, 6,3V/3A en parallèle ou 12,6V/1,5A en série,
même puissance dans les deux cas) — pas les 10W de validation initiale
ci-dessus. §3/§4 du même document avaient déjà fait, à la main (formule
idéale D/(1-D)=Vout/Vin, sans SPICE), le calcul de marge courant à ce
point précis : Irms primaire 3,37A / secondaire 4,45A vs limite datasheet
MSD1514-103ME 7,6A (« one winding »), marges ×2,26/×1,71. Cette passe
vérifie ce calcul par SPICE et répond à la question motivant l'UCC24612 :
**le redressement synchrone règle-t-il, en plus du rendement, le
dépassement Vds_Q2>100V déjà trouvé à 10W (§2) ?**

Aucun modèle SPICE sourcé n'existe pour l'UCC24612 (contrôleur analogique
à détection de Vds, pas de macromodèle publié par TI) — même situation
que la Schottky générique du §2bis. Proxy retenu, même esprit : Q2 reste
le vrai sous-circuit IPD050N10N5 (diode de corps toujours présente
pendant le temps mort), grille pilotée par un PULSE idéal complémentaire
à Q1 (temps mort 100ns) — approxime une diode emulation parfaite, **pas**
une simulation du composant réel ni une mesure. Implémenté dans
`simulation/gen_asc.py` (`rectifier="sync_ideal"`), en branchant le
paramètre `dead` de `build()` qui existait déjà dans la signature mais
n'était utilisé nulle part.

Méthode (conforme à la discipline « simple d'abord, un changement à la
fois ») : D trouvé par `find_duty.py` (modèle Schottky rapide déjà
validé) aux mêmes 6 coins Vin×Vout que l'enveloppe 10W mais à
Rload=Vout²/18,9 (2,1Ω au coin 6,3V, 8,4Ω au coin 12,6V) ; D réutilisé tel
quel pour la passe `sync_ideal` (pas re-résolu pour le modèle réel — la
puissance réellement délivrée dérive donc de 18,8 à 22,3W selon le point,
voir tableaux). `simulation/run_envelope_18w9.py`,
`simulation/results/envelope_18w9_schottky.csv`,
`simulation/results/envelope_18w9_sync.csv`.

**Passe 1 — Schottky idéal (même modèle rapide déjà validé à 10W, seule
la puissance change) :**

| Point | Vin | D | Vout | Pout | η | Ipk pri | Irms pri | Vds Q1 max | Vds Q2 max |
|---|---|---|---|---|---|---|---|---|---|
| 11V→6,3V  | 11V | 0,4006 | 6,38V | 19,38W | 85,6% | 6,19A | 3,29A | 54,9V | 20,0V |
| 11V→12,6V | 11V | 0,5502 | 12,60V | 18,89W | 90,7% | 4,90A | 2,64A | 53,5V | 25,5V |
| 20V→6,3V  | 20V | 0,2602 | 6,29V | 18,82W | 86,1% | 5,40A | 2,17A | 54,2V | 30,0V |
| 20V→12,6V | 20V | 0,4006 | 12,76V | 19,39W | 89,8% | 4,61A | 1,85A | 53,4V | 47,2V |
| 25V→6,3V  | 25V | 0,2194 | 6,33V | 19,09W | 85,3% | 5,30A | 1,92A | 54,3V | 35,3V |
| 25V→12,6V | 25V | 0,3462 | 12,70V | 19,20W | 87,9% | 4,57A | 1,64A | 53,5V | 44,2V |

Vds_Q2 reste modéré partout (≤47V) — **comme au §2bis**, le modèle Schottky
idéal ne reproduit pas la résonance non-linéaire du MOSFET réel, ces
chiffres ne disent rien sur le risque de dépassement 100V.

**Passe 2 — IPD050N10N5 réel + grille Q2 synchrone idéale (proxy
UCC24612) :**

| Point | Vin | D | Vout | Pout | η | Ipk pri | Irms pri | Vds Q1 max | Vds Q2 max | Perte redresseur |
|---|---|---|---|---|---|---|---|---|---|---|
| 11V→6,3V  | 11V | 0,4006 | 6,80V | 22,04W | 91,2% | 7,07A | 3,54A | 54,9V | **63,2V** | 0,32W |
| 11V→12,6V | 11V | 0,5502 | 13,09V | 20,41W | 94,2% | 5,30A | 2,81A | 52,3V | 86,3V | 0,20W |
| 20V→6,3V  | 20V | 0,2602 | 6,73V | 21,56W | 91,8% | 6,74A | 2,42A | 54,4V | **100,6V** ⚠ | 0,31W |
| 20V→12,6V | 20V | 0,4006 | 13,31V | 21,08W | 94,8% | 5,13A | 2,02A | 51,7V | **106,7V** ⚠ | 0,23W |
| 25V→6,3V  | 25V | 0,2194 | 6,85V | 22,32W | 92,8% | 7,01A | 2,17A | 52,2V | **106,7V** ⚠ | 0,44W |
| 25V→12,6V | 25V | 0,3462 | 13,22V | 20,80W | 93,5% | 5,04A | 1,78A | 52,4V | **106,8V** ⚠ | 0,29W |

(Point 11V→6,3V : première tentative non convergente — `results/
point18w9_sync_ideal_11V_6V3.log` coupe net après les warnings de
largeur de MOSFET, aucun résultat — même symptôme intermittent que §6.
Relancé à l'identique, convergé sans autre changement.)

### Verdict

**Courant/saturation — pas un facteur limitant, confirme le calcul à la
main (§3/§4 du document d'intention).** Pire cas réel observé (11V→6,3V,
retenté) : Ipk=7,07A vs Isat 10%-drop=13,4A (marge ×1,9, et toujours sous
le 20%-drop=15,0A) ; Irms=3,54A vs 7,6A one-winding (marge ×2,15) —
`msd1514.pdf` p.2. Même avec la puissance réellement délivrée dérivant
jusqu'à 22,3W (au-dessus du haut de la fourchette demandée), aucune marge
courant n'est entamée.

**Rendement — l'UCC24612 apporte un gain réel et substantiel à cette
puissance.** Comparaison aux mêmes D/Vin/Vout (ex. 20V→12,6V) :
89,8%→94,8% (+5,0 points), perte redresseur secondaire 0,70W→0,23W.
Confirme la motivation initiale (la diode de corps seule, à 18-20W,
dissiperait trop pour rester un choix raisonnable).

**⚠ Vds_Q2 — le redressement synchrone NE règle PAS le dépassement
100V, et la situation est PIRE qu'à 10W.** Avec le modèle réel + grille
synchrone, Vds_Q2 dépasse déjà 100V (tenue IPD050N10N5, `ipd050n10n5.yaml`
vds_max) **dès Vin=20V** (100,6V) — pas seulement Vin≥23V comme à 10W
(§2) — et plafonne vers 106,7-106,8V sur tout le haut de la plage Vin
(20-25V), quel que soit le coin Vout. Seul Vin=11V reste largement sous
la limite (63,2V). Cohérent avec l'hypothèse posée en entrant dans cette
passe : c'est un phénomène de résonance d'inductance de fuite
(proportionnel à Ipk², donc à la puissance), **indépendant du mode de
redressement** — l'UCC24612 améliore le rendement mais ne change rien au
risque de claquage de Q2.

**D1 (clamp primaire) — toujours large marge.** Pire cas observé (passe
sync_ideal, 11V→6,3V) : 0,91W vs 5W (`smcj43a.yaml` P_av) — pas un point
dur, même conclusion qu'au §2bis.

**Conclusion : 18-20W n'est pas tenable en l'état (sans clamp secondaire),
même avec l'UCC24612.** Le point ouvert déjà identifié en
`00-intention-conception.md` §10 (« Snubber/clamp éventuel côté
secondaire ... pas encore traité ») passe de souhaitable à
**bloquant** pour viser cette puissance — l'UCC24612 reste pertinent pour
le rendement mais ne peut pas se substituer à un clamp sur Q2. Avant toute
décision matérielle : dimensionner ce clamp (TVS ou RCD, à partir de
l'énergie de fuite au nouveau Ipk, cf. méthode déjà utilisée pour D1 en
`00-intention-conception.md` §6) et le valider par une nouvelle passe
SPICE avec ce clamp réellement modélisé, avant de modifier le schéma
KiCad.

**Réserves à garder en tête** (mêmes limites que §3, §6 ci-dessus,
inchangées par cette passe) : `Lmesh_sec`/`Cinter_ESTIME` toujours
quasi nuls (non sourcés) — la résonance réelle sur PCB est probablement
**sous-estimée**, pas surestimée, donc ces chiffres ne sont pas
pessimistes par excès de prudence. Proxy `sync_ideal` ≠ UCC24612 réel (pas
de modèle du comparateur/des seuils réels de détection Vds, pas de
dynamique VDD/REG). D non re-résolu pour la passe réelle (Pout dérive de
18,8 à 22,3W selon le point, cf. tableau) — lecture qualitative valable,
pas un point de fonctionnement pinné exactement à 18,9W.

## 7bis. Clamp secondaire — SMCJ43A (même réf. que D1) vs SMCJ54A, dissipation chiffrée

Suite directe du verdict §7 (clamp secondaire bloquant pour viser
18-20W). Deux candidats TVS Bourns (`bourns-smcj-series.pdf` p.2, même
construction modèle que D1 : BV + IBV=1mA + RS=1Ω à partir des 2 points
datasheet, exploratoire, pas encore une fiche composant retenue) montés
en D2sec (même orientation que D1 : anode=masse secondaire,
cathode=drain Q2), modèle réel + synchrone idéal (proxy UCC24612), mêmes
6 points/D que §7 :

- **SMCJ43A** (Vbr_min=47,8V, Vc=69,4V@21,7A) — même référence que D1,
  déjà au BOM.
- **SMCJ54A** (Vbr_min=60V, Vc=87,1V@17,3A) — candidat alternatif à seuil
  plus haut.

`simulation/run_sec_clamp_candidates.py`,
`simulation/results/sec_clamp_candidates.csv`.

| Point | Vin | SMCJ43A : Vds_Q2 clampé | SMCJ43A : P(D2sec) | SMCJ54A : Vds_Q2 clampé | SMCJ54A : P(D2sec) |
|---|---|---|---|---|---|
| 11V→6,3V  | 11V | 50,0V | 0,12W | 61,0V | 0,03W |
| 11V→12,6V | 11V | 51,3V | 0,33W | 63,0V | 0,21W |
| 20V→6,3V  | 20V | 52,0V | 0,49W | 63,7V | 0,34W |
| 20V→12,6V | 20V | 52,5V | 0,81W | 64,4V | 0,53W |
| 25V→6,3V  | 25V | 52,8V | 0,86W | 64,7V | 0,59W |
| 25V→12,6V | 25V | 52,9V | **1,29W** | 64,9V | **0,76W** |

**Réponse à la question posée (dissipation du SMCJ43A proposé)** : 0,12W
à 1,29W selon le point, pire cas 25V→12,6V. Marge vs le P_av=5W de la
série SMCJ (`smcj43a.yaml` / `bourns-smcj-series.pdf` p.1) : **×3,9 au
pire cas** — pas un point dur. Et il fait le travail : Vds_Q2 clampé à
~50-53V partout, marge ×1,9 vs les 100V du MOSFET. Contrairement à
l'inquiétude initiale (un seuil aussi bas que 47,8V pourrait conduire en
continu pendant le fonctionnement normal, pas seulement pendant le pic de
résonance), la dissipation réelle reste modeste — le clamp écrête bien le
sommet de la résonance mais ne conduit pas assez longtemps par cycle pour
peser lourd en moyenne.

**Où part l'énergie non dissipée dans le SMCJ54A ? Pas dans un autre
poste de pertes — elle n'est simplement plus tirée de Vin.** Décomposition
complète (mêmes 6 points, log LTspice relus en entier, pas juste
Ploss_D2sec) au pire coin (25V→12,6V) :

| | SMCJ43A | SMCJ54A | Δ |
|---|---|---|---|
| Pin_avg | 23,133W | 22,615W | **-0,518W** |
| Pout_avg | 20,848W | 20,838W | -0,010W (quasi identique) |
| Ploss_Q1 | 0,712W | 0,718W | +0,006W (identique) |
| Ploss_DCR1/DCR2/Rshunt/Cout (somme) | 0,152W | 0,150W | -0,002W (identique) |
| Ploss_D2sec | 1,293W | 0,756W | -0,537W |

Même constat (Pin baisse de ~0,5V, tous les autres postes inchangés,
seul le clamp lui-même varie) sur les 6 points — le tableau complet est
dans `results/point18w9_clamp_*.log`. Q1, les DCR, Rshunt, Cout ne
bougent quasiment pas entre les deux candidats : l'énergie "en moins"
dans le SMCJ54A **n'est pas redistribuée ailleurs dans le circuit**,
elle n'est simplement plus allée chercher côté primaire. Le couplage
K1 L1 L2 relie les deux résonances (primaire et secondaire) : écrêter
plus bas/plus tôt côté secondaire (SMCJ43A) modifie la dynamique vue par
le primaire et fait tirer davantage sur Vin pour un Pout quasi identique
— un vrai surcoût de rendement, pas juste un déplacement de chaleur d'un
composant à l'autre.

**Conséquence directe sur le rendement système**, même alignement D que
§7 (donc comparaison directe, un seul paramètre changé = le seuil du
clamp) :

| Point | η SMCJ43A | η SMCJ54A | Δ |
|---|---|---|---|
| 11V→6,3V  | 91,31% | 91,15% | -0,16 pt |
| 11V→12,6V | 93,42% | 93,73% | +0,31 pt |
| 20V→6,3V  | 91,85% | 92,55% | +0,70 pt |
| 20V→12,6V | 92,44% | 93,65% | +1,21 pt |
| 25V→6,3V  | 90,47% | 90,83% | +0,36 pt |
| 25V→12,6V | 90,12% | 92,15% | **+2,03 pt** |

**Recommandation révisée : SMCJ54A**, pas SMCJ43A. L'argument
« même référence que D1 » ne pèse pas lourd face à un gain de rendement
système réel et reproductible sur 5 des 6 points (jusqu'à +2 points au
pire coin) — et la marge de tension reste confortable (×1,5 vs 100V,
contre ×1,9 pour le SMCJ43A, les deux largement suffisants). La
dissipation du composant lui-même n'était de toute façon un point dur
pour aucun des deux candidats (×3,9 et ×7 de marge vs 5W respectivement)
— ce n'est donc pas le critère qui doit trancher ; le rendement, oui.

**Toujours ouvert avant de construire** : ce modèle clamp est construit
sur 2 points datasheet comme D1, pas encore vérifié avec les parasites
réels de PCB (`Lmesh_sec`/`Cinter_ESTIME` quasi nuls, §3/§7) — à
revalider une fois le routage connu. Orientation/empreinte D2sec à
choisir au placement, même discipline que D1
(`00-intention-conception.md` §6, `smcj43a.yaml` pinmap).

## Méthode

Simulation préparée avec Claude Code (LTspice 26.1.1, mode batch).
Modèle MOSFET réel fourni par l'utilisateur (bibliothèque Infineon
OptiMOS5 100V, téléchargée directement depuis infineon.com). Vérifié à la
main : cohérence Pin/Pout par point, garde-fou anti-collision de coordonnées
dans le générateur (`simulation/gen_asc.py`, a déjà révélé un bug réel de
câblage lors d'une passe précédente), mode de conduction lu sur la forme
d'onde plutôt que supposé.

Fichiers pour rejouer la simulation : `simulation/`.

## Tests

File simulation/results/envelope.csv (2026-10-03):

label | vin | vout_target | d | rload | vout_avg | iout_avg | pout_avg | pin_avg | eta_pct | mode | ploss_q1 | ploss_q2body | ploss_dcr1 | ploss_dcr2 | ploss_rshunt | ploss_cout | ploss_sum | ploss_total_pin_pout | vds_q1_max | vds_q2_max | ipk_pri | irms_pri | il2_end_of_period
11V_6V | 11.0 | 6.0 | 0.3828 | 3.6 | 5.964 | 1.6567 | 9.8805 | 11.6246 | 85.0 | CCM | 0.176 | 1.2717 | 0.0511 | 0.0773 | 0.0255 | 0.0077 | 1.6093 | 1.7441 | 49.798 | 57.427 | 4.134 | 1.8462 | 1.7349
11V_12V | 11.0 | 12.0 | 0.5359 | 14.4 | 11.9764 | 0.8317 | 9.9607 | 11.0445 | 90.19 | CCM | 0.1537 | 0.6546 | 0.0398 | 0.0348 | 0.02 | 0.0053 | 0.9082 | 1.0837 | 49.422 | 74.412 | 3.4138 | 1.6296 | 0.3562
20V_6V | 20.0 | 6.0 | 0.25 | 3.6 | 5.9597 | 1.6555 | 9.8661 | 11.6275 | 84.85 | CCM | 0.1786 | 1.2884 | 0.0285 | 0.0691 | 0.0146 | 0.006 | 1.5852 | 1.7614 | 49.551 | 88.532 | 4.2622 | 1.379 | 1.0425
20V_12V | 20.0 | 12.0 | 0.3016 | 14.4 | 11.9039 | 0.8267 | 9.8405 | 10.8211 | 90.94 | DCM | 0.1646 | 0.5937 | 0.0216 | 0.0314 | 0.0109 | 0.0046 | 0.8268 | 0.9806 | 49.37 | 75.686 | 3.7543 | 1.1988 | 0.1529
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

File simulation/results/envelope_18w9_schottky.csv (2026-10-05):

label | vin | vout_target | d | rload | vout_avg | iout_avg | pout_avg | pin_avg | eta_pct | mode | ploss_q1 | ploss_rect | ploss_d1 | ploss_dcr1 | ploss_dcr2 | ploss_rshunt | ploss_cout | ploss_sum | ploss_total_pin_pout | vds_q1_max | vds_q2_max | ipk_pri | irms_pri | il2_end_of_period
11V_6V3 | 11.0 | 6.3 | 0.4006 | 2.1 | 6.3798 | 3.038 | 19.382 | 22.6329 | 85.64 | CCM | 1.1883 | 1.4745 | 1.0375 | 0.1619 | 0.2363 | 0.0799 | 0.0211 | 4.1995 | 3.2509 | 54.909 | 20.032 | 6.191 | 3.2851 | 4.1603
11V_12V6 | 11.0 | 12.6 | 0.5502 | 8.4 | 12.5955 | 1.4995 | 18.8866 | 20.8339 | 90.65 | CCM | 0.9295 | 0.7014 | 0.809 | 0.1044 | 0.0816 | 0.0516 | 0.0104 | 2.6879 | 1.9473 | 53.464 | 25.494 | 4.9006 | 2.6383 | 1.8803
20V_6V3 | 20.0 | 6.3 | 0.2602 | 2.1 | 6.287 | 2.9938 | 18.8224 | 21.8739 | 86.05 | CCM | 1.2585 | 1.4216 | 1.1251 | 0.0705 | 0.1893 | 0.0344 | 0.0118 | 4.1112 | 3.0515 | 54.219 | 30.036 | 5.3976 | 2.1686 | 2.8541
20V_12V6 | 20.0 | 12.6 | 0.4006 | 8.4 | 12.7616 | 1.5192 | 19.388 | 21.5831 | 89.83 | CCM | 1.3094 | 0.6979 | 1.1546 | 0.0512 | 0.07 | 0.025 | 0.0076 | 3.3157 | 2.1951 | 53.42 | 47.217 | 4.6126 | 1.8483 | 0.648
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

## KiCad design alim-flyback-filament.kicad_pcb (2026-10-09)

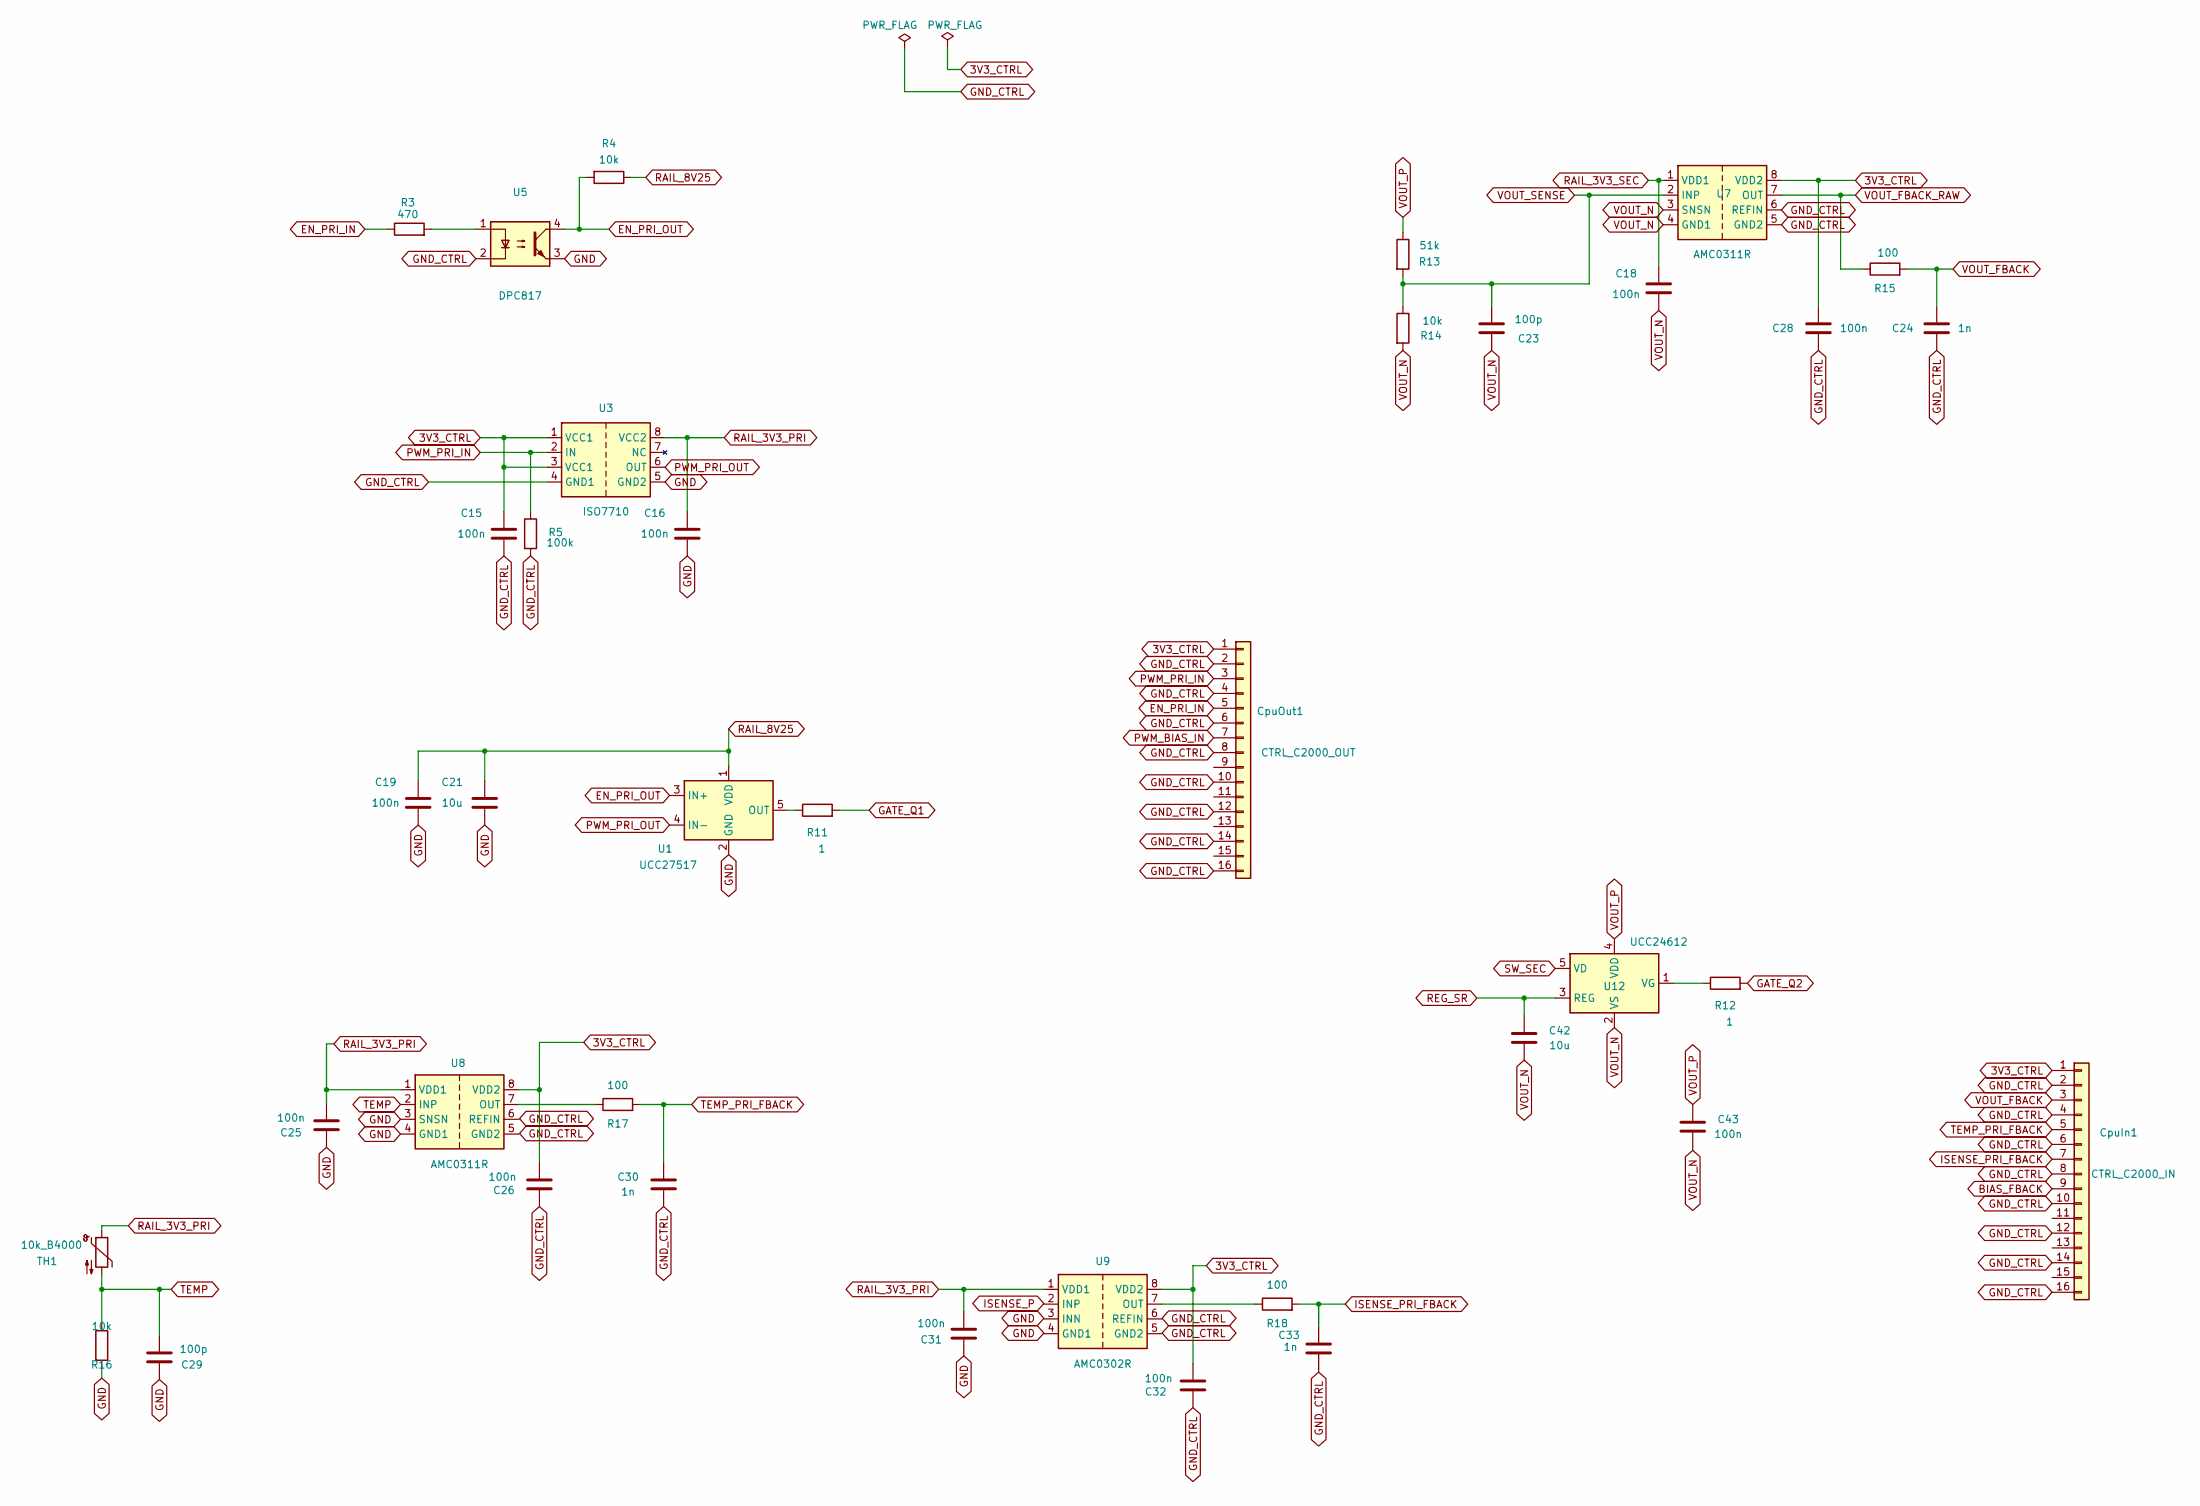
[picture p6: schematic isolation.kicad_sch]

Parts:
C15, C16, C18, C19, C25, C26, C28, C31, C32, C43: 100n; C_0805_2012Metric
C21, C42: 10u; C_0805_2012Metric
C23, C29: 100p; C_0805_2012Metric
C24, C30, C33: 1n; C_0805_2012Metric
CpuIn1: CTRL_C2000_IN; PinHeader_2x08_P2.54mm_Vertical
CpuOut1: CTRL_C2000_OUT; PinHeader_2x08_P2.54mm_Vertical
R3: 470; R_0805_2012Metric
R4, R14, R16: 10k; R_0805_2012Metric
R5: 100k; R_0805_2012Metric
R11, R12: 1; R_0805_2012Metric
R13: 51k; R_0805_2012Metric
R15, R17, R18: 100; R_0805_2012Metric
TH1: 10k_B4000; R_0805_2012Metric
U1: UCC27517; SOT-23-5
U3: ISO7710; SOIC-8_3.9x4.9mm_P1.27mm
U5: DPC817; SMDIP-4_W7.62mm
U7, U8: AMC0311R; SOIC-8_DWV_5.85x11.5mm_P1.27mm
U9: AMC0302R; SOIC-8_DWV_5.85x11.5mm_P1.27mm
U12: UCC24612; SOT-23-5

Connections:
3V3_CTRL: C15.1, C26.1, C28.1, C32.1, CpuIn1.1, CpuOut1.1, U3.1 (VCC1), U3.3 (VCC1), U7.8 (VDD2), U8.8 (VDD2), U9.8 (VDD2); also elsewhere on the board
BIAS_FBACK: CpuIn1.9; also elsewhere on the board
EN_PRI_IN: CpuOut1.5, R3.1
EN_PRI_OUT: R4.2, U1.3 (IN+), U5.4
GATE_Q1: R11.2; also elsewhere on the board
GATE_Q2: R12.2; also elsewhere on the board
GND: C16.2, C19.2, C21.2, C25.2, C29.2, C31.2, R16.2, U1.2 (GND), U3.5 (GND2), U5.3, U8.3 (SNSN), U8.4 (GND1), U9.3 (INN), U9.4 (GND1); also elsewhere on the board
GND_CTRL: C15.2, C24.2, C26.2, C28.2, C30.2, C32.2, C33.2, CpuIn1.2, CpuIn1.4, CpuIn1.6, CpuIn1.8, CpuIn1.10, CpuIn1.12, CpuIn1.14, CpuIn1.16, CpuOut1.2, CpuOut1.4, CpuOut1.6, CpuOut1.8, CpuOut1.10, CpuOut1.12, CpuOut1.14, CpuOut1.16, R5.2, U3.4 (GND1), U5.2, U7.5 (GND2), U7.6 (REFIN), U8.5 (GND2), U8.6 (REFIN), U9.5 (GND2), U9.6 (REFIN); also elsewhere on the board
ISENSE_P: U9.2 (INP); also elsewhere on the board
ISENSE_PRI_FBACK: C33.1, CpuIn1.7, R18.2
unnamed: R3.2, U5.1
unnamed: R11.1, U1.5 (OUT)
unnamed: R17.1, U8.7 (OUT)
unnamed: R18.1, U9.7 (OUT)
unnamed: R12.1, U12.1 (VG)
PWM_BIAS_IN: CpuOut1.7; also elsewhere on the board
PWM_PRI_IN: CpuOut1.3, R5.1, U3.2 (IN)
PWM_PRI_OUT: U1.4 (IN-), U3.6 (OUT)
RAIL_3V3_PRI: C16.1, C25.1, C31.1, TH1.1, U3.8 (VCC2), U8.1 (VDD1), U9.1 (VDD1); also elsewhere on the board
RAIL_3V3_SEC: C18.1, U7.1 (VDD1); also elsewhere on the board
RAIL_8V25: C19.1, C21.1, R4.1, U1.1 (VDD); also elsewhere on the board
REG_SR: C42.2, U12.3 (REG)
SW_SEC: U12.5 (VD); also elsewhere on the board
TEMP: C29.1, R16.1, TH1.2, U8.2 (INP)
TEMP_PRI_FBACK: C30.1, CpuIn1.5, R17.2
VOUT_FBACK: C24.1, CpuIn1.3, R15.2
VOUT_FBACK_RAW: R15.1, U7.7 (OUT)
VOUT_N: C18.2, C23.2, C42.1, C43.1, R14.2, U7.3 (SNSN), U7.4 (GND1), U12.2 (VS); also elsewhere on the board
VOUT_P: C43.2, R13.1, U12.4 (VDD); also elsewhere on the board
VOUT_SENSE: C23.1, R13.2, R14.1, U7.2 (INP)

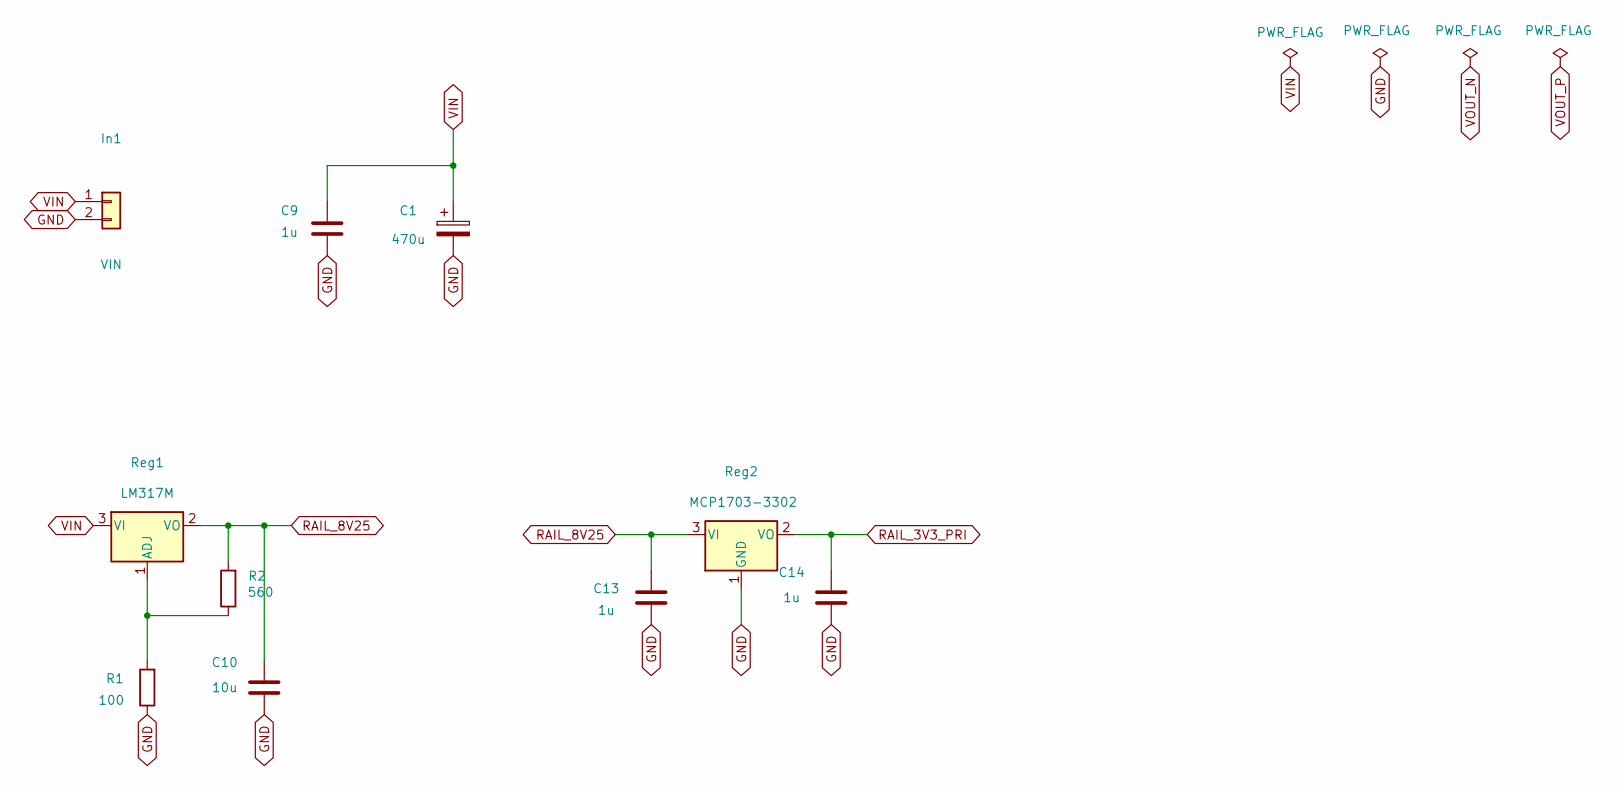
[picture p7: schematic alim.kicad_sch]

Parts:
C1: 470u; A786MW_VChip
C9, C13, C14: 1u; C_0805_2012Metric
C10: 10u; C_0805_2012Metric
In1: VIN; PinHeader_1x02_P2.54mm_Vertical
R1: 100; R_0805_2012Metric
R2: 560; R_0805_2012Metric
Reg1: LM317M; SOT-223-3_TabPin2
Reg2: MCP1703-3302; SOT-23-3

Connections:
GND: C1.2, C9.2, C10.2, C13.2, C14.2, In1.2, R1.1, Reg2.1 (GND); also elsewhere on the board
unnamed: R1.2, R2.1, Reg1.1 (ADJ)
RAIL_3V3_PRI: C14.1, Reg2.2 (VO); also elsewhere on the board
RAIL_8V25: C10.1, C13.1, R2.2, Reg1.2 (VO), Reg2.3 (VI); also elsewhere on the board
VIN: C1.1, C9.1, In1.1, Reg1.3 (VI); also elsewhere on the board

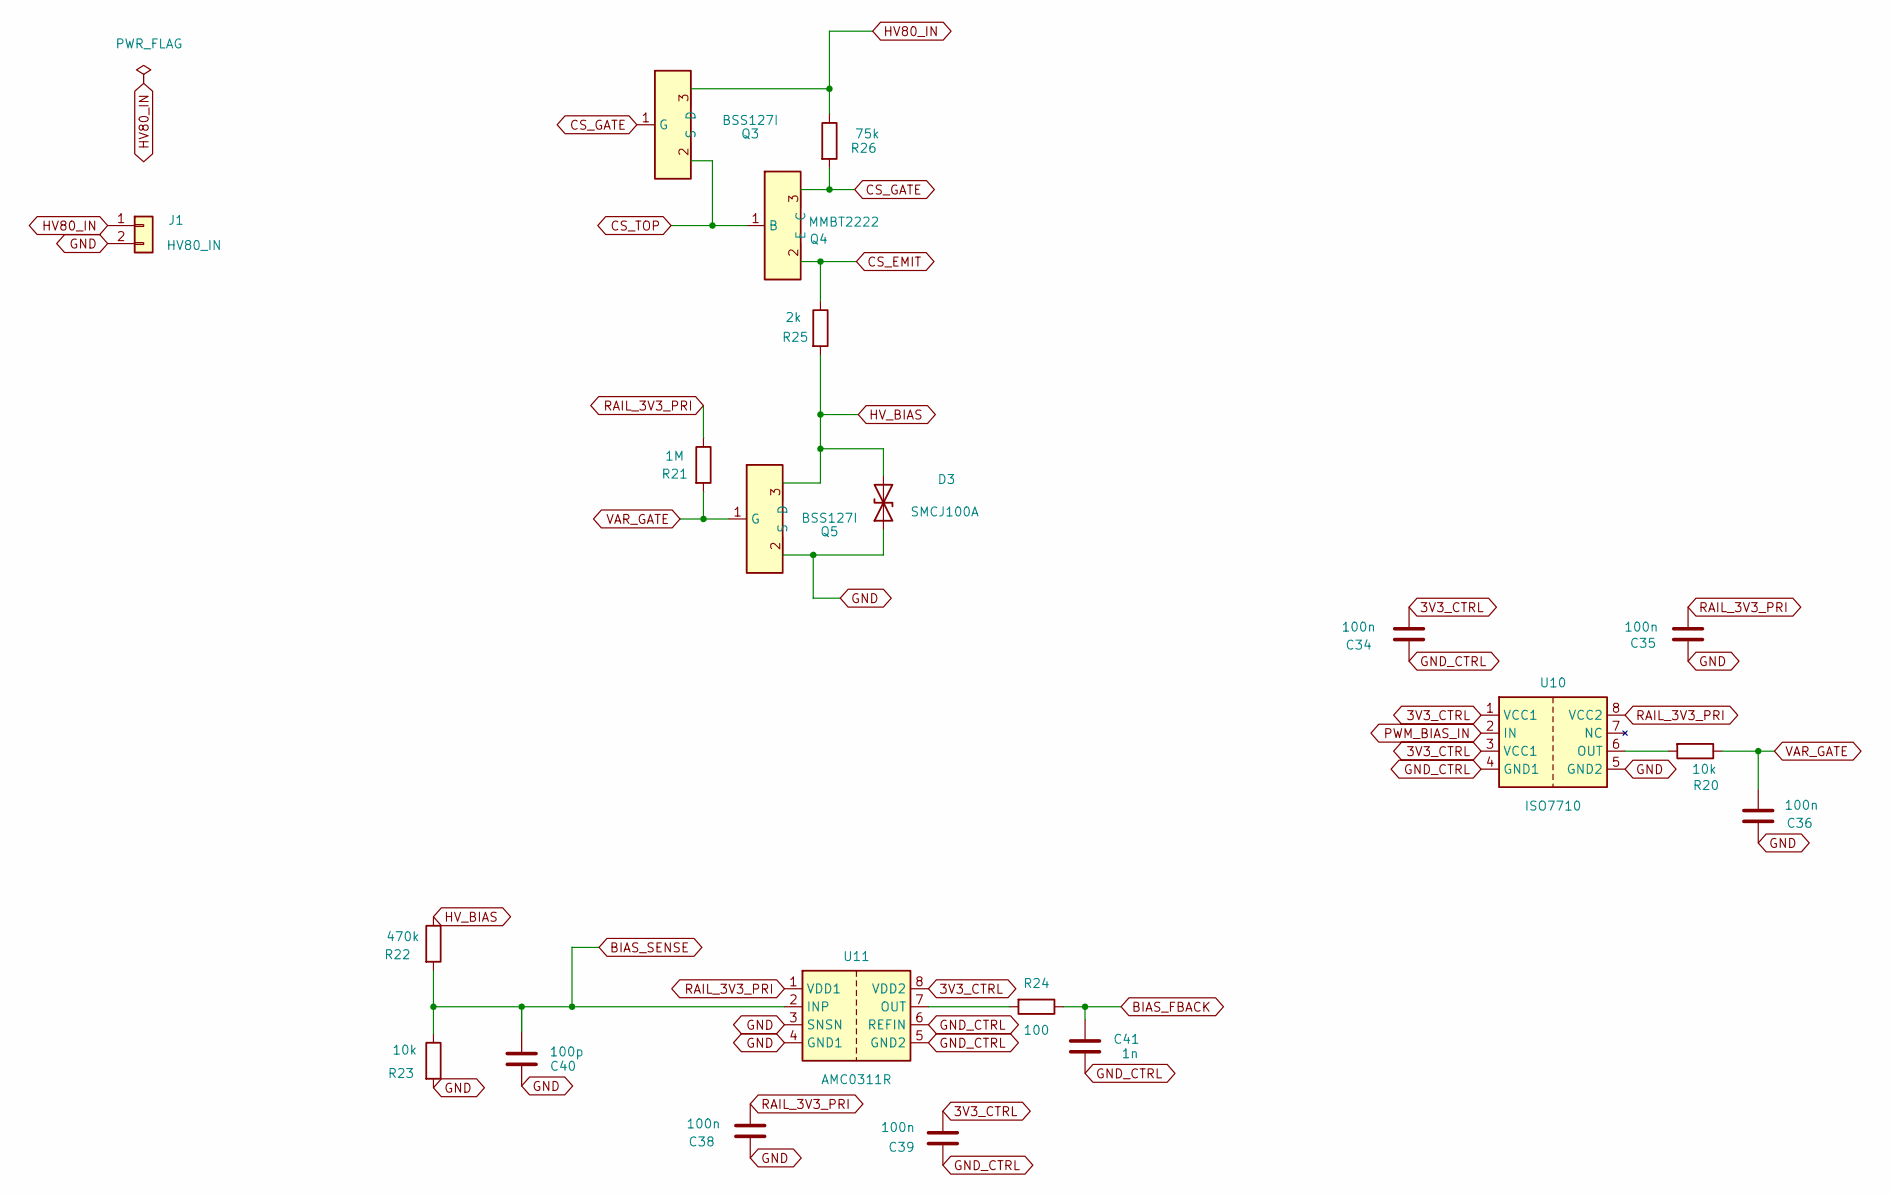
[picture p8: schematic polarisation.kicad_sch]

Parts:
C34, C35, C36, C38, C39: 100n; C_0805_2012Metric
C40: 100p; C_0805_2012Metric
C41: 1n; C_0805_2012Metric
D3: SMCJ100A; D_SMC
J1: HV80_IN; PinHeader_1x02_P2.54mm_Vertical
Q3, Q5: BSS127I; SOT-23
Q4: MMBT2222; SOT-23
R20, R23: 10k; R_0805_2012Metric
R21: 1M; R_0805_2012Metric
R22: 470k; R_0805_2012Metric
R24: 100; R_0805_2012Metric
R25: 2k; R_0805_2012Metric
R26: 75k; R_0805_2012Metric
U10: ISO7710; SOIC-8_3.9x4.9mm_P1.27mm
U11: AMC0311R; SOIC-8_DWV_5.85x11.5mm_P1.27mm

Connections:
3V3_CTRL: C34.1, C39.1, U10.1 (VCC1), U10.3 (VCC1), U11.8 (VDD2); also elsewhere on the board
BIAS_FBACK: C41.1, R24.1; also elsewhere on the board
BIAS_SENSE: C40.1, R22.2, R23.1, U11.2 (INP)
CS_EMIT: Q4.2 (E), R25.1
CS_GATE: Q3.1 (G), Q4.3 (C), R26.2
CS_TOP: Q3.2 (S), Q4.1 (B)
GND: C35.2, C36.2, C38.2, C40.2, D3.1 (A1), J1.2, Q5.2 (S), R23.2, U10.5 (GND2), U11.3 (SNSN), U11.4 (GND1); also elsewhere on the board
GND_CTRL: C34.2, C39.2, C41.2, U10.4 (GND1), U11.5 (GND2), U11.6 (REFIN); also elsewhere on the board
HV80_IN: J1.1, Q3.3 (D), R26.1
HV_BIAS: D3.2 (A2), Q5.3 (D), R22.1, R25.2; also elsewhere on the board
unnamed: R20.2, U10.6 (OUT)
unnamed: R24.2, U11.7 (OUT)
PWM_BIAS_IN: U10.2 (IN); also elsewhere on the board
RAIL_3V3_PRI: C35.1, C38.1, R21.1, U10.8 (VCC2), U11.1 (VDD1); also elsewhere on the board
VAR_GATE: C36.1, Q5.1 (G), R20.1, R21.2

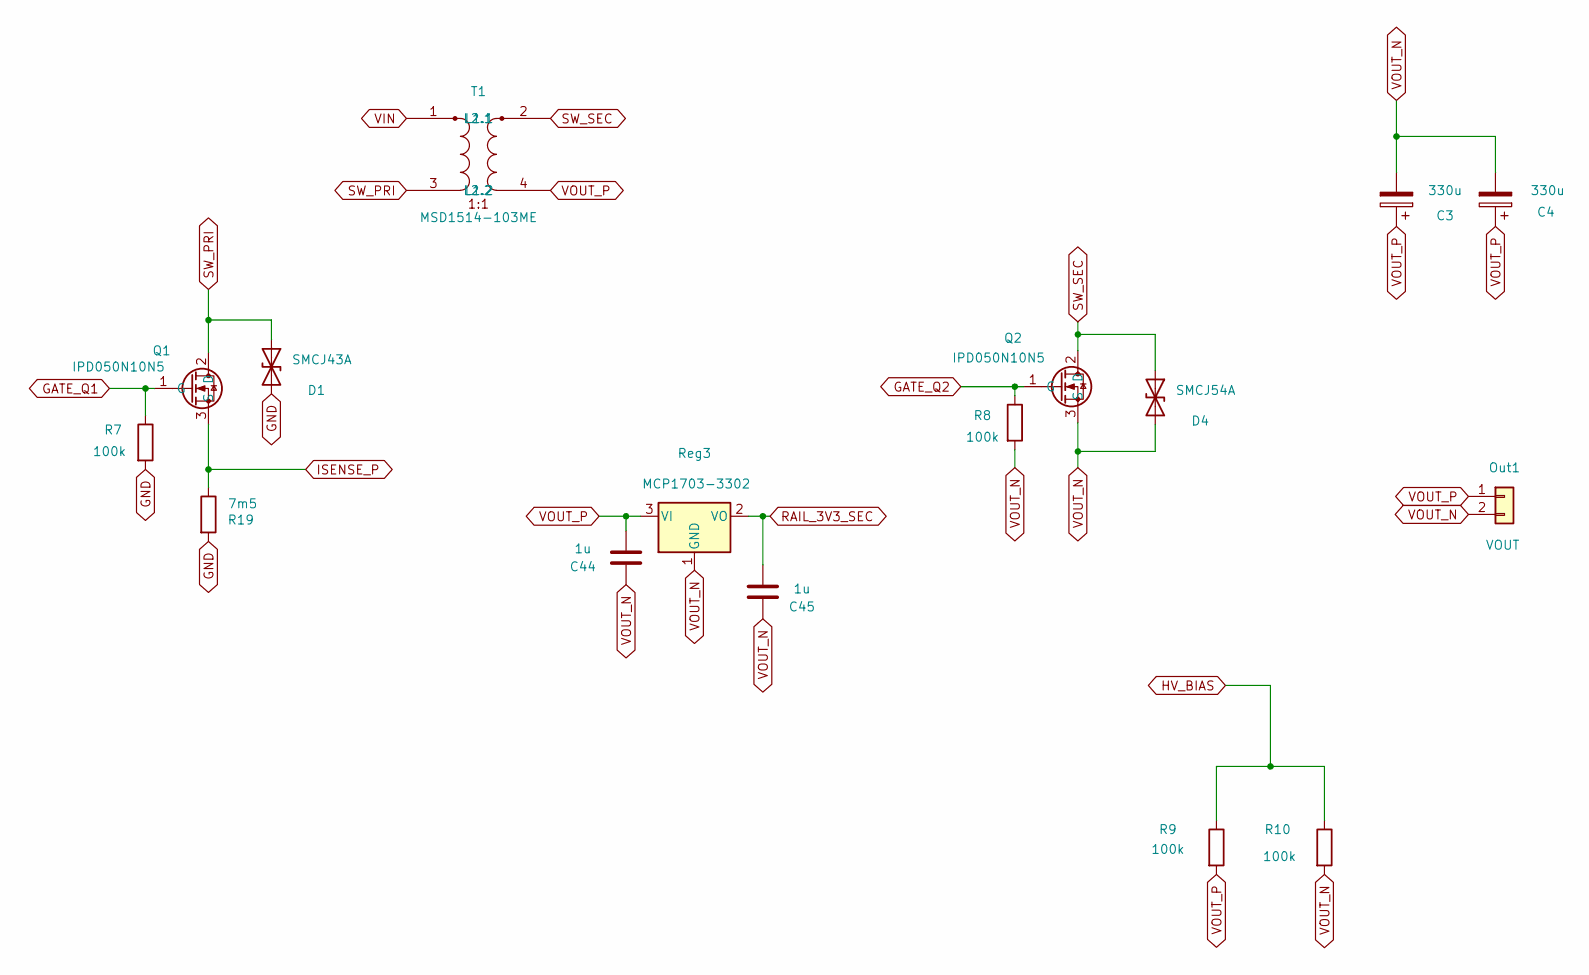
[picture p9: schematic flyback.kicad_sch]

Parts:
C3, C4: 330u; CP_Elec_6.3x9.9
C44, C45: 1u; C_0805_2012Metric
D1: SMCJ43A; D_SMC
D4: SMCJ54A; D_SMC
Out1: VOUT; PinHeader_1x02_P2.54mm_Vertical
Q1, Q2: IPD050N10N5; TO252-3_TabPin2
R7, R8, R9, R10: 100k; R_0805_2012Metric
R19: 7m5; R_1210_3225Metric
Reg3: MCP1703-3302; SOT-23-3
T1: MSD1514-103ME; MSD1514

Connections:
GATE_Q1: Q1.1 (G), R7.1; also elsewhere on the board
GATE_Q2: Q2.1 (G), R8.1; also elsewhere on the board
GND: D1.2 (A2), R7.2, R19.2; also elsewhere on the board
HV_BIAS: R9.1, R10.1; also elsewhere on the board
ISENSE_P: Q1.3 (S), R19.1; also elsewhere on the board
RAIL_3V3_SEC: C45.1, Reg3.2 (VO); also elsewhere on the board
SW_PRI: D1.1 (A1), Q1.2 (D), T1.3 (L1.2)
SW_SEC: D4.1 (A1), Q2.2 (D), T1.2 (L2.1); also elsewhere on the board
VIN: T1.1 (L1.1); also elsewhere on the board
VOUT_N: C3.2, C4.2, C44.2, C45.2, D4.2 (A2), Out1.2, Q2.3 (S), R8.2, R10.2, Reg3.1 (GND); also elsewhere on the board
VOUT_P: C3.1, C4.1, C44.1, Out1.1, R9.2, Reg3.3 (VI), T1.4 (L2.2); also elsewhere on the board

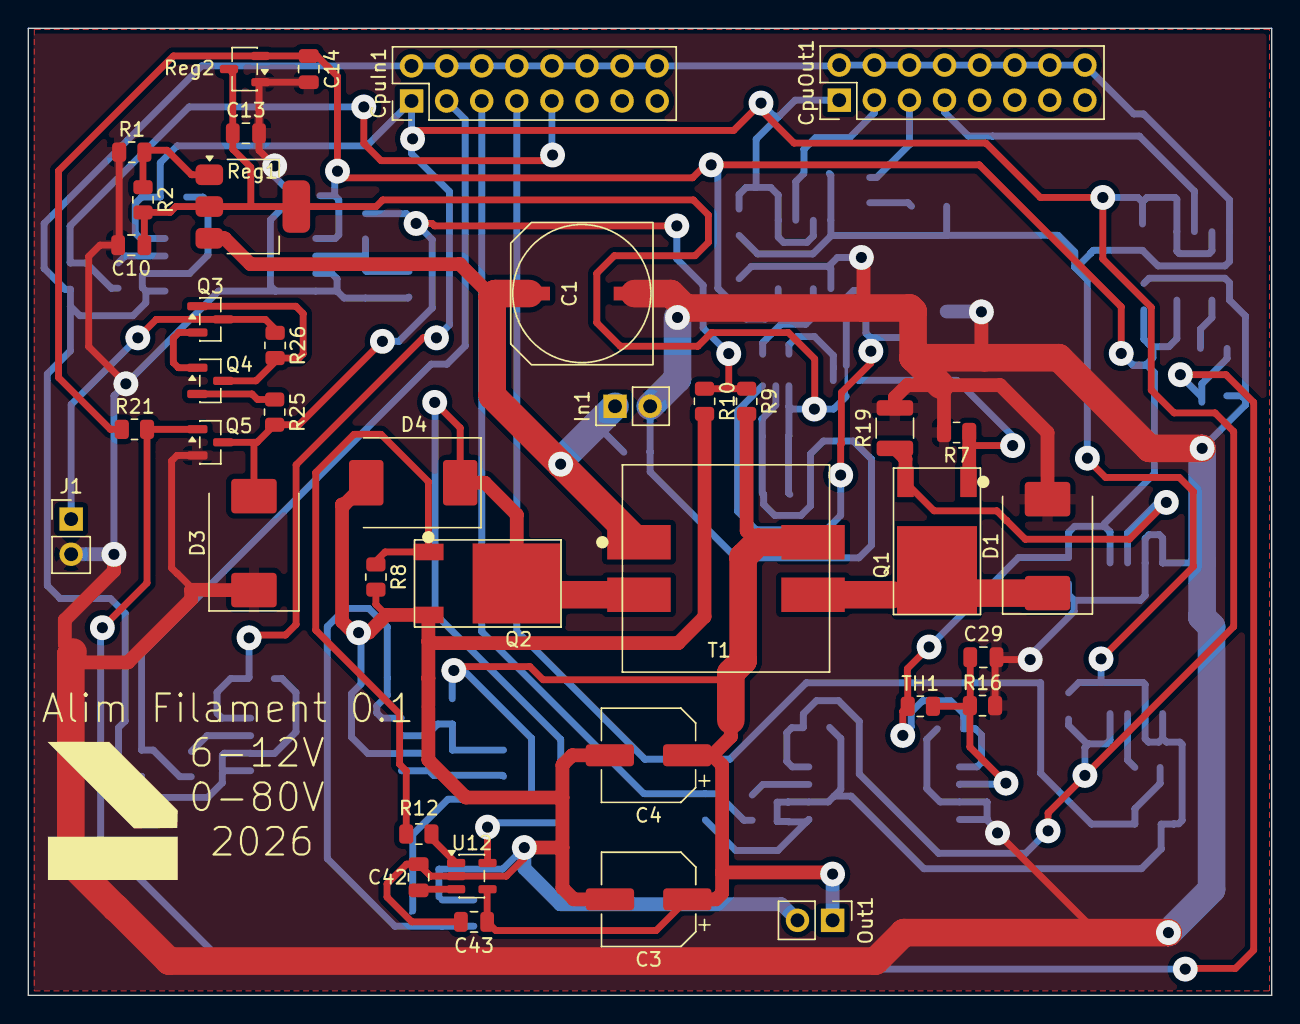
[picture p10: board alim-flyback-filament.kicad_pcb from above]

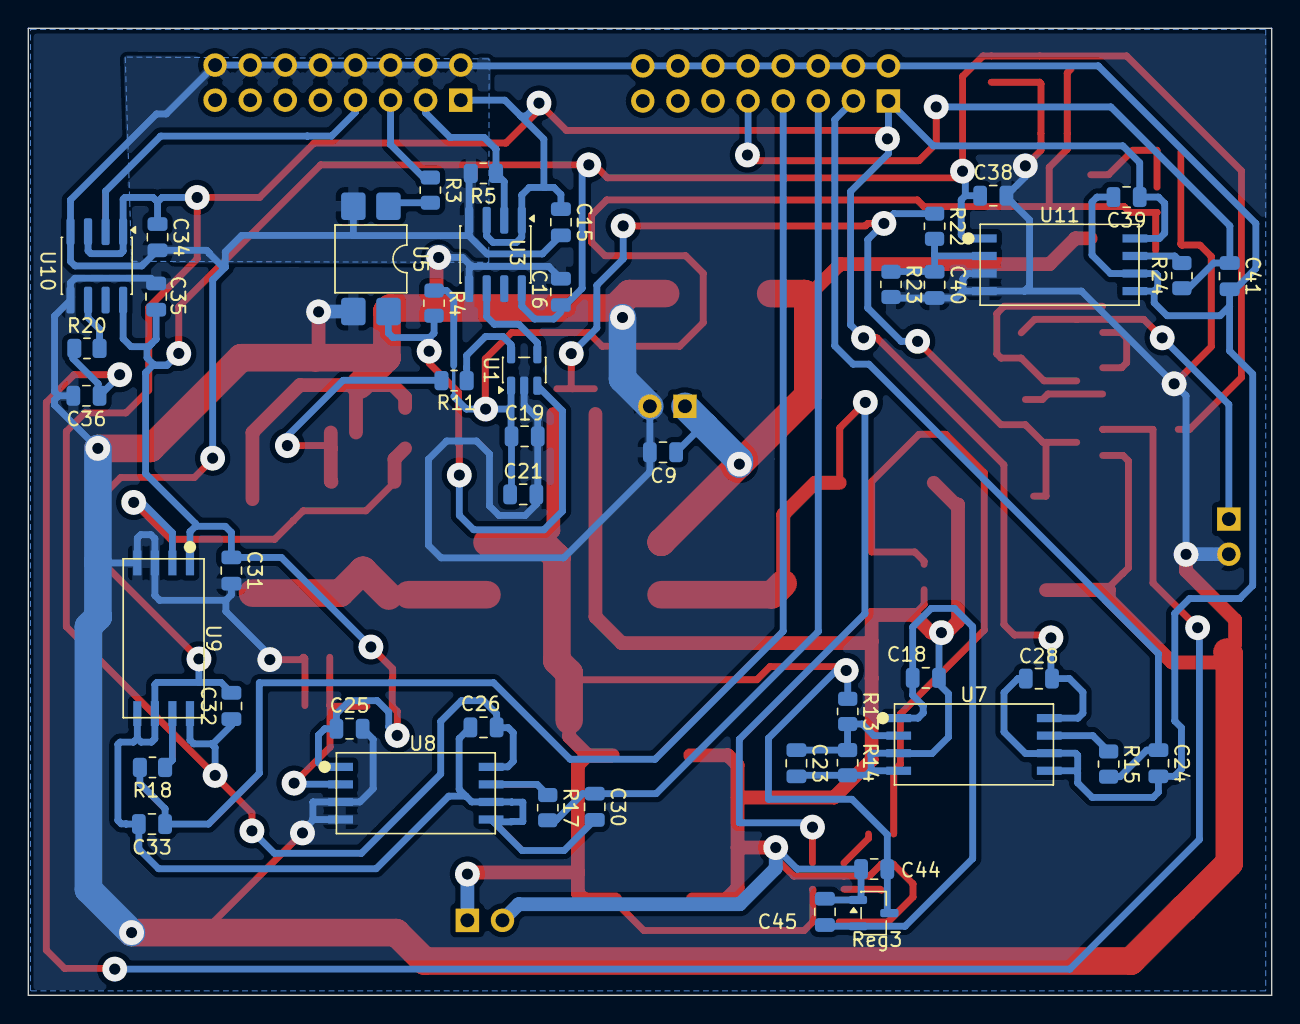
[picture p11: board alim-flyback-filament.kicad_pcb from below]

Board: 2 copper layers, 90.0 x 70.0 mm, 85 parts (46 on the bottom side), 42 nets.

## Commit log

2026-09-30 Import initial : alimentation flyback flottante filament + préampli
    Flyback isolé 200kHz, 11-25V→5,5-13V/3A, secondaire flottant élevable
    0-90V par pont 2×100k. Schéma hiérarchique (3 feuilles), symboles et
    empreintes custom (MSD1514, TO-252, KEMET A786MW), ERC clean.
    [alim-flyback-filament.kicad_pcb, alim-flyback-filament.kicad_sch, alim.kicad_sch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]
2026-10-02 Secondaire ISO7710+UCC27517 conservé, ajout retour Vout isolé AMC0311S, modèles 3D
    - D2 (bootstrap) remplacé par BAT54C (cathode commune) pour compatibilité pinout
    - AMC0311S (U7) ajouté : retour de mesure Vout isolé vers le connecteur C2000
    - Connecteur Cpu1 étendu à 8 broches (signaux + masses)
    - Correction pastilles Gate/Source sur l'empreinte custom TO-252 (pin1/pin3 inversées)
    - Modèles 3D attachés aux empreintes custom (TO-252, MSD1514, A786MW V-chip)
    - Image de rendu 3D ajoutée au README
    [alim-flyback-filament.kicad_pcb, flyback.kicad_sch, isolation.kicad_sch]
2026-10-02 Isolation C2000 réelle (GND_CTRL/3V3_CTRL) + feuille Polarisation (HV_BIAS actif 0-90V)
    - U3/U4/U5/U7/U8/U9 migrés côté contrôle vers GND_CTRL/3V3_CTRL (isolation
    du C2000 réellement effective, plus seulement nominale)
    - Connecteurs CpuOut/CpuIn agrandis 2x04→2x08 (16 broches), marge pour
    futurs signaux et compatibilité avec d'autres cartes
    - Nouvelle feuille polarisation.kicad_sch : pilotage actif de HV_BIAS
    (point de polarisation du secondaire flottant) depuis une alimentation
    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
    [alim-flyback-filament.kicad_pcb, alim-flyback-filament.kicad_sch, alim.kicad_sch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]
2026-10-03 Retours temperature/courant primaire isoles, isolation C2000 reelle, feuille Polarisation finalisee (80V, R26 corrige par simulation)
    - U8 (AMC0311R) : retour temperature primaire (thermistance NTC) isole
    - U9 (AMC0302R) : retour courant primaire (shunt R19) isole
    - Migration GND_CTRL/3V3_CTRL : le C2000 externe recoit ses propres nets
    d'alimentation/masse isoles (U3/U4/U5/U7/U8/U9), connecteurs CpuOut/CpuIn
    agrandis a 16 broches
    - Feuille polarisation.kicad_sch reprise en etiquettes globales uniquement
    (plus de fils explicites) et alignee sur la grille 1.27mm
    - Source de courant Q3/Q4/R25/R26 simplifiee a un rail fixe 80V (HV80_IN,
    ex-400V) ; R26 corrige de 2M7 a 75k apres simulatio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
    [alim-flyback-filament.kicad_pcb, alim-flyback-filament.kicad_sch, alim.kicad_sch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]
2026-10-03 Simulation flyback etapes 1-4 : modeles reels (MOSFET Infineon, clamp D1), enveloppe 10W
    - Modele MOSFET reel IPD050N10N5 (sous-circuit SPICE officiel Infineon
    OptiMOS5, fourni par l'utilisateur) remplace le substitut IPD068N10N3,
    utilise pour Q1 et pour le redressement passif (diode de corps de Q2 -
    pas de Schottky discret dans le vrai chemin de puissance secondaire).
    - Clamp primaire D1 modelise sur 2 points sources de la datasheet
    SMCJ43A (Vbr=47,8V@1mA, Vc=69,4V@21,7A), oriente correctement
    (unidirectionnel, cathode cote switch node).
    - Garde-fou anti-collision de coordonnees conserve dans le generateur
    (gen_asc.py) - deja utile pour attraper les erreurs de cablage tot.
    - Bal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
    [envelope.csv]
2026-10-03 Comparaison modele simplifie (Schottky) vs diode de corps reelle + perte clamp D1
    - gen_asc.py : parametre rectifier=schottky/body_diode (Q1 et D1
    restent reels dans les deux cas). Mesure dediee de la perte dans D1
    (clamp), absente jusqu'ici - c'etait l'inquietude explicite de
    l'utilisateur.
    - Schottky generique nettement plus rapide a simuler (35-40s vs 35-90s,
    convergence plus robuste) pour un rendement 1,5-3,5 points plus
    optimiste que le modele reel - ordre de grandeur rapide, pas un
    chiffre de conception final.
    - Perte clamp D1 substantielle et croissante avec Vin (327mW a 891mW),
    confirme l'inquietude - marge thermique correcte (x5,6 au pire point
    vs P_av=5W de la datas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
    [envelope_schottky.csv]
2026-10-05 Validation 18,9W + redressement synchrone : UCC24612 (U12) remplace U2/U4, clamp D4 ajouté
    Simulation SPICE à la cible réelle (18,9W, pas les 10W de validation initiale) :
    Vds_Q2 dépasse 100V dès Vin=20V sans clamp secondaire, indépendamment du
    redresseur. UCC24612 amène +5pts de rendement mais ne corrige pas la
    surtension -- D4 (SMCJ54A) ajouté pour ça. U2/U4 retirés (timing firmware
    aveugle, remplacé par la détection Vds de l'UCC24612).
    [alim-flyback-filament.kicad_pcb, alim.kicad_sch, envelope_18w9_schottky.csv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]
2026-10-05 README : architecture secondaire à jour (UCC24612/D4) + figures 18,9W
    Le README décrivait encore l'ancien secondaire (UCC27517+ISO7710 piloté
    PWM, bootstrap) -- mis à jour pour UCC24612 (détection Vds, alimenté
    direct depuis Vout) + clamp D4. Ajout des figures manquantes dans la
    section Validation (10W + 18,9W + comparaison clamp), générées par deux
    nouveaux scripts (make_plots_18w9.py, make_plots_clamp.py) sur le même
    modèle que les scripts existants.
2026-10-05 README : résumé chiffré + paragraphe anglais en tête, pour la visibilité externe
    Trois lignes de chiffres (rendement 18,9W, gain redressement synchrone,
    surtension résolue par le clamp) et un paragraphe anglais sous le titre --
    beaucoup d'outils de sourcing et de recruteurs lisent en anglais en premier.
    Le contenu français détaillé reste inchangé en dessous.
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2026-10-09 Mise a jour routage PCB, resultats de simulation, et renommage du depot devkit
    alim-flyback-filament.kicad_pcb : progression du routage. Nouveaux
    resultats de simulation (clamp SMCJ43A/54A, comparaison Schottky,
    enveloppe eta/Vds). 00-intention-conception.md : reference au depot
    devkit renomme (shield-c2000 -> KICAD-C2000-devkit).
    [alim-flyback-filament.kicad_pcb]
2026-10-18 Finalise le renommage alim-flyback-filament -> KICAD-HT et partage TO252
    - Renommage du depot (fichiers deja renommes localement, jamais commite) :
    KICAD-HT.kicad_pcb/.kicad_pro/.kicad_sch, doc/KICAD-HT.png, references
    mises a jour (README.md, gen_composants.py PROJECT=, 00-intention-
    conception.md, doc/sim-vs-mesure.md, simulation/gen_asc.py).
    alim/isolation/polarisation.kicad_sch : resauvegarde native KiCad
    (reformatage), pas de changement electrique.
    - bom_family_report.py : plus de chemin KiCad code en dur, detection
    dynamique du titre de projet (deja fait en session precedente, jamais
    commite).
    - TO252 bascule vers la bibliotheque partagee lib_fp_commun/ (voir
    KICAD.md)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
2026-10-21 Bascule les empreintes custom (MSD1514, A786, SOIC_DWV) et logos (lebel/pcbway) vers lib_fp_commun
    Supprime les copies locales redondantes, ajoute Symbol_commun/Graphic
    (bibliotheques standard KiCad partagees) au fp-lib-table. Les logos
    places sur le PCB passent du nickname lebel/lib au nickname partage
    artwork (lib_id renomme directement sur les instances, pas de symbole
    schema pour ces footprints decoratifs).
2026-10-21 Remplace CpuOut1/CpuIn1 par un connecteur J2 unique, aligné pin-a-pin sur J21 du shield
    KICAD-C2000-powershield a desormais un connecteur IDC 2x10 dedie
    (J21/NAPPE_FILAMENT_HT, decision #26) a la place du partage de nappes
    generiques. J2 reprend exactement ce brochage ; 7 nets renommes pour
    matcher le vocabulaire du shield (PWM_ht, PWM_EN, PWM_bias, Vht,
    Temp_ht, I_Shunt_ht, V_bias, 3V3_ISO). GND_CTRL volontairement non
    renomme en GND : KICAD-HT a deja un net GND distinct (masse primaire
    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
2026-10-21 Ajoute les symboles custom pour la limitation de courant locale
    WSK1206R0100FEA (shunt Kelvin 4 broches), SN74LVC1G132/1G74/1G08
    (logique), BAT54S (copié de Power_Parts, déjà utilisé côté powershield),
    TSV791, LMV7219, ATL431 -- brochages sourcés datasheet, préparent
    l'implémentation de §19 (00-intention-conception.md). Footprint
    WSK1206 nettoyé dans lib_fp_commun et enregistré dans fp-lib-table.
2026-10-21 R19 passe à 10mOhm, Yageo WSK1206R0100FEA 4 broches Kelvin
    Remplace le 7,5mOhm/1210/2 broches par le shunt Kelvin sourcé par
    l'utilisateur. Pastilles 2/4 (force) reprennent exactement la position
    des pins de l'ancien Device:R -- aucun fil/label existant du chemin
    ISENSE_P/GND à retoucher. Pastilles 1/3 (sense, mapping confirmé par
    l'utilisateur) exposées en nouveaux labels ISNS_KP/ISNS_KN, consommés
    par la future feuille limitation-courant.
2026-10-21 Gate IN+ de U1 via un AND (SN74LVC1G08), U9 déplacé sur le Kelvin de R19
    IN- de U1 est déjà occupé par PWM_PRI_OUT (pas disponible pour le
    verrou comme le supposait le prompt de départ) : ajoute U13
    (SN74LVC1G08), EN_PRI_GATED = EN_PRI_OUT AND nQ_TRIP, branché sur IN+ à
    la place de EN_PRI_OUT direct. U3 non touché (ISO7710 reste ISO7710F
    casserait le défaut-sûr actuel, voir 00-intention-conception.md §19).
    U9 (AMC0302R) lit maintenant ISNS_KP/ISNS_KN (pastilles Kelvin de R19)
    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
2026-10-21 Documente §19 : limitation de courant locale, écarts corrigés, suivi YAML
    00-intention-conception.md : motivation, les 3 écarts corrigés par
    rapport au prompt d'origine (U3 reste ISO7710, gating sur IN+ via AND,
    connecteur déjà prêt), substitutions de pièces actées avec l'utilisateur,
    méthode de calcul du seuil/gain, table de vérité du verrou, limites
    connues, état de la vérification ERC. Signale explicitement que les
    fiches YAML composants-datasheets de cette passe ne sont pas produites
    (pinmap nécessite une capture PCB impossible ici, double-extraction en
    worktree séparé non faite, ATL431/LMV7219 hors familles existantes du
    schéma) -- suivi à faire séparément plutôt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
2026-10-22 Ajoute une LED de defaut sur Q_TRIP (R34/D6), corrige un bug d'insertion lib_symbols
    Q_TRIP (sortie de reserve du verrou) recoit un usage reel : LED rouge 3mm
    + 10k, polarite ajustee par l'utilisateur pour s'allumer en defaut latche
    (Q_TRIP -> D6 -> R34 -> GND, verifie par export netlist).
    Corrige au passage une insertion incorrecte du bloc lib_symbols de
    Device:LED (imbrique par erreur dans l'etiquette globale ISNS_AMP au lieu
    de suivre la vraie fermeture de lib_symbols), qui empechait le chargement
    de la feuille. Documente dans l'addendum du S19.
2026-10-22 Retouches manuelles : notation ~{} pour nPRE/nQ_TRIP, RAIL_8V25->RAIL_3V3_PRI, via 1.0/0.4mm
    Renomme nPRE et nQ_TRIP en notation KiCad overline (~{PRE}/~{Q_TRIP}),
    corrige une etiquette RAIL_8V25 en RAIL_3V3_PRI dans isolation.kicad_sch,
    ajuste la taille de via par defaut (1.8/0.8 -> 1.0/0.4mm) et progresse sur
    le placement/routage PCB.
2026-10-23 Ajoute F1 (fusible VIN) et D2 (TVS RAIL_8V25), documente le plan d'isolation
    Deux composants poses par l'utilisateur dans alim.kicad_sch pour fermer
    les chemins 1 et 2 du confinement de defaut (doc/plan-isolation-4couches.md,
    S8) : F1 en serie sur VIN, D2 (SMCJ10A) entre RAIL_8V25 et GND. Verifies
    par calcul de position de broche (pas seulement par label) et par
    rechargement standalone + hierarchie complete.
    Nomenclature verifiee : D5/D6/D7/R30-R32 proposes par le plan
    collisionnaient avec limitation-courant.kicad_sch (S19, posterieur au
    commit de base du plan) -- corrige dans le plan, prochains reperes
    libres D8/R35-R37. Documente dans S20 de 00-intention-conception.md.
    Ignore aussi les e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
2026-10-23 Resistances de reference inter-domaines (3x1M par barriere), F1 a 3A
    Ajoute les trois chaines de resistances 1M en serie (R35/R6/R36,
    R37/R38/R39, R42/R41/R40) qui ferment le point ouvert du plan
    d'isolation (S3) : reference DC entre les trois domaines sans degrader
    la CMTI. Chaine plutot qu'une resistance unique -- un seul 0805 n'a que
    0,8mm d'ecart cuivre entre ses pastilles, loin des 8,5mm vises.
    F1 fixe a 3A. TVS directe sur VIN retiree de la liste : deja presente
    sur KICAD-C2000-powershield, en amont au niveau systeme.
    Nomenclature reverifiee sur tout le projet, aucune collision. Fichiers
    touches revalides (equilibre parentheses conscient des chaines,
    chargement standalone + hierarchi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
2026-10-23 Corrige la contrainte d'isolation a 4mm (ISO7710 D-8 = Basic, pas Reinforced)
    Verifie dans iso7710.pdf (S5.6) : le boitier D-8 (SOIC-8 etroit) reellement
    monte pour U3/U10/U19 est explicitement classe "Basic Insulation",
    CLR/CPG=4mm -- le renforce 8,5mm n'existe que sur la variante DW-16, non
    montee. Les AMC0302R/AMC0311R (U8/U9/U11) restent en boitier large
    reinforced, DPC817 (U5) mesure a ~5mm. Barriere entiere alignee sur 4mm
    (uniforme) plutot que varier par composant.
    Ajoute la regle .kicad_dru "meme_composant" (A.Reference == B.Reference)
    en exception avant la regle generale de barriere, necessaire car les 7
    isolateurs violeraient sinon la contrainte a leurs propres broches --
    syntaxe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
2026-10-23 Cree les classes de nets CTRL/PRI et le fichier .kicad_dru (regle corrigee)
    Ajoute les classes CTRL/PRI dans KICAD-HT.kicad_pro avec 40 nets assignes,
    verifies un par un via export netlist (pas par motif de nom suppose).
    Ajoute KICAD-HT.kicad_dru avec la regle de barriere a 4mm.
    Corrige au passage la regle elle-meme : une regle d'exception separee
    pour "meme composant" (A.Reference == B.Reference, testee aussi avec 8
    regles explicites par isolateur) ne fonctionne pas -- verifie par DRC
    reel, 139 violations identiques avant/apres. L'exclusion doit etre dans
    la condition de la regle de barriere elle-meme (A.Reference !=
    B.Reference) : 139 -> 36 violations mesure apres correction. Documente
    da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
2026-10-27 Linearisation HV_BIAS : composants reels en simulation, correctif Rs+Cint
    Rejoue la boucle de linearisation (MCP6001 + Q6/Q7) avec des modeles
    reels (MMBF170, MCP6001 parametre depuis sa datasheet) plutot que des
    modeles ideaux/generiques : revele une oscillation auto-entretenue
    invisible sur le schema seul, confirmee independante du proxy MOSFET
    et non liee a la bande passante de l'ampli-op (teste avec un TSV791
    plus rapide, resultat pire).
    Correctif valide en simulation avant report sur le schema : resistance
    de degenerescence Rs=330 sur la source de Q6/Q7 (supprime l'oscillation
    sans sacrifier l'acces a HV_BIAS=0V) + condensateur de compensation
    Cint=1nF autour de l'ampli-op (supprime le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
2026-10-27 Linearisation HV_BIAS : stabilise sous PWM reel (Rs=1k/Cint=100p), placement Q7
    Le correctif precedent (Rs=330/Cint=1nF) n'avait ete valide qu'avec un
    echelon analogique deja filtre, pas le vrai PWM du C2000. En rejouant la
    boucle avec le PWM reel, elargir le filtre d'entree pour ecraser
    l'ondulation residuelle (R47/Cin : 1k/1n -> 100k/100n) a reintroduit une
    oscillation auto-entretenue differente (~700kHz), confirmee independante
    du PWM via un echelon direct isole avant le filtre.
    Nouveau correctif, verifie sur le profil complet de commande PWM (3,5s) :
    Rs=1k (degenerescence Q6, au lieu de 330) + Cint=100pF (compensation
    ampli-op, au lieu de 1nF) -- ondulation residuelle en sortie sous le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
2026-10-28 Routage en cours : retouches schema (alim/flyback/isolation/limitation-courant/polarisation), doc renommage Temp_ht->I_Out_ht et NAPPE_FILAMENT_HT->DC_HT, fix .kicad_dru (commentaires #), nettoyage s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
2026-10-28 Via-stitching GND_CTRL (grille 5mm, F.Cu/In1.Cu/B.Cu, 13 vias) ; retrait du via VOUT_N pose au mauvais endroit, methode corrigee documentee
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2026-10-29 Corrige le contour silkscreen des 4 isolateurs SOIC-8 DWV (U7/U9/U11/U22) : cote traversait les pastilles, -32 violations DRC silk_over_copper
2026-10-29 Corrige le point de broche 1 (cercle silkscreen) du SOIC-8 DWV, meme cause que le contour : epaisseur de trait non comptee, -4 violations
2026-10-29 Corrige le motif de la classe CTRL : Temp_ht -> I_Out_ht (renommage de net jamais repercute ici), -10 fausses violations d'isolation barriere_controle
2026-10-29 Ajoute l'exemption clearance pastilles-meme-composant (meme motif que KICAD-HV/U13) : U18 VSSOP-8 pas 0,65mm, 0,15mm reel vs 0,2mm netclasse PRI, -5 fausses violations
2026-10-29 Ajoute Q5_LED_K a la classe CTRL : pastille du MOSFET Q4 (pilote LED de l'optocoupleur U20, source sur GND_CTRL), sous-circuit cote controle jamais classe
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2026-10-29 Corrige silk_over_copper Q1/Q2/Q5/T1/C1 et ajoute VODA1275 a fp-lib-table
    Repercute dans les empreintes placees (copies embarquees du .kicad_pcb)
    la correction de contour apportee a TO252-3_TabPin2/MSD1514/A786MW_VChip
    dans lib_fp_commun -- KiCad ne resynchronise pas automatiquement une
    empreinte placee quand le fichier librairie change, il fallait editer
    les deux. Ajoute aussi l'entree VODA1275 manquante dans fp-lib-table
    (bibliotheque presente sur disque et deja utilisee par U20, jamais
    enregistree ici -- presente dans KICAD-HV, oubliee ici).
    41 -> 23 avertissements DRC (0 regression verifiee par diff avant/apres).
2026-10-29 Corrige le sliver VOUT_N/GND, remet les trous de fixation, fixe le 3D de F1
    Travail de nettoyage silkscreen (texte titre, champs reference, J2) et
    contour de zone (pointe de cuivre VOUT_N pres du via RAIL_8V25, decouverte
    via reconstruction geometrique des zones remplies faute de coordonnees
    dans le rapport DRC). Modele 3D de F1 repointe vers
    Fuseholder_Cylinder-5x20mm_Schurter_0031_8201_Horizontal_Open.step
    (echelle 0.836 pour coller au pas 18.8mm existant) -- le fichier original
    Littelfuse_111_Lateral n'a jamais existe dans la bibliotheque 3D KiCad
    stock (verifie sur le depot officiel), aucune pastille ni routage touche.
    DRC propre (0 violation).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
2026-10-29 Documente la fin du routage et le nettoyage DRC final (silkscreen, sliver, F1)
    00-intention-conception.md : §27 (TO252/MSD1514/A786MW_VChip, VODA1275,
    decouverte du cache de copie embarquee .kicad_pcb), §28 (pointe de cuivre
    VOUT_N/GND localisee par reconstruction geometrique, modele 3D F1), §29
    (routage termine, DRC 0 violation). Corrige aussi la mention obsolete du
    contour 70x55mm en §12 (carte reellement a 85x70mm).
    README.md : statut routage a jour (fait, plus "etape manuelle suivante"),
    nouvelle ligne dans le tableau de validation.
2026-10-29 Ajoute la regle de clearance haute tension HT_distance_90V (frontiere SEC)
    Aucune netclasse/regle ne couvrait les nets qui montent a 90V (secondaire
    elevable) -- ils heritaient de la clearance generique 0,2mm comme un net
    logique. Verifie avec le vrai moteur DRC sur une copie jetable.
    Seuil : 1,1mm en externe (F.Cu/B.Cu), formule HT-02/IPC-9592B pour
    convertisseurs a 100V (0,1+0,01*V), deja le choix de reference du projet
    pour ce type de carte. Pas de regle separee en interne (le plancher
    0,2mm par defaut couvre deja HT-02 la).
    Frontiere par netclasse SEC vs non-SEC (meme motif que barriere_controle),
    pas par une liste de 5 noms de nets -- une premiere version nommait les
    nets et les compa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
2026-10-29 Resout le retour de masse isole de J2 (remove_unused_layers signal)
    Les 10 broches GND_CTRL de J2 etaient en grande partie isolees du plan
    principal sur F.Cu/In1.Cu/B.Cu : relief thermique sur chaque broche GND
    combine a l'absence de place laissee par la pastille signal voisine
    (meme rangee, pas 2,54mm). Teste et ecarte : reduction manuelle de
    pastille signal sur In1.Cu seul (couronne sous le plancher DRC/Multi-CB
    a 1,2mm, 0,3mm de pont a peine suffisant) ; reduction isolee du
    clearance GND_CTRL<->signal de J2 a 0,15mm (regle J2_clearance_reduite_essai,
    conservee a titre documentaire, aucun effet mesure seule).
    Solution retenue : remove_unused_layers=yes + keep_end_layers=yes sur
    les 10 bro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
2026-10-29 Ajoute Q8/U5 (driver optocoupleur PWM_EN) et classe Net-(Q8-D) en CTRL
    Q8 (MMBF170, NMOS) pilote U5 (DPC817) pour ne pas charger le
    microcontroleur sur PWM_EN. Le net Net-(Q8-D) (drain Q8 <-> cathode U5)
    tombait hors de la netclasse CTRL par defaut, declenchant 14 violations
    barriere_controle contre ses voisins CTRL (R3, C34, U10, R37) pourtant
    dans le meme sous-circuit. Verifie par tracage (Q8 gate=PWM_EN,
    source=GND_CTRL ; U5 anode via R3=3V3_ISO) avant classement, comme pour
    les ajouts precedents a SEC. DRC : 14 erreurs -> 0.
    Documente aussi le fix du retour de masse J2 (§30, remove_unused_layers
    sur les 10 broches signal).
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2026-11-01 Points de test TP10-TP20 : nom de net en Value, Reference masquee
    - isolation.kicad_sch : Value de TP10-TP20 corrigee (etait "G_Q1"/
    "GND_ISO" en placeholder copie-colle) -> vrai nom de net, verifie via
    netlist KiCad (3V3_ISO, PWM_ht, PWM_EN, PWM_bias, Vht_EN, Vht,
    I_Out_ht, I_Shunt_ht, I_Shunt_ht_comp, V_bias, GND_CTRL -- les 11
    signaux de J2).
    - KICAD-HT.kicad_pcb : meme traitement que TP3-TP9 (Reference masquee,
    Value visible sur F.SilkS) applique a TP10-TP20.
    - TP20 chevauche une zone 3V3_ISO sur In2.Cu (clearance 0mm) -- erreur
    DRC bloquante, pas corrigee ici, a traiter separement (placement).
    - alim.kicad_sch / flyback.kicad_sch : TP1/TP2/TP21 (8V25/3V3P/GND) et
    reorganis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
2026-11-11 Doc: corrige le decompte ERC (6 feuilles, pas 3), le lien composants-datasheets casse, et signale l'ecart de fuite a resimuler
    ERC: 6 feuilles reelles (alim/flyback/isolation/limitation-courant/
    polarisation+racine), 1 erreur reelle (U13 pin2) plutot que "0 erreur sur
    3 feuilles". Lien composants-datasheets (depot interne, non public) retire,
    remplace par une mention texte. CSV de simulation/results/ clarifies comme
    non versionnes (gitignore, trop volumineux) plutot que presentes comme
    presents. Avertissement ajoute sur les chiffres 94.8%/106.8V : simulation
    K1 L1 L2 0.99 (~0.20uH fuite) vs 0.40uH datasheet utilise pour le calcul
    d'energie du clamp -- ecart x2, a resimuler.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
2026-11-11 Corrige le net orphelin nQ_TRIP/~{Q_TRIP} sur isolation.kicad_sch (ERC 0 erreur)
    U13 broche B portait un label "nQ_TRIP" (convention prefixe "n"), alors
    que le reste du projet nomme ce signal "~{Q_TRIP}" (notation KiCad a
    barre de negation) sur limitation-courant.kicad_sch, pilote par U18.
    Deux noms differents = deux nets separes, U13 broche B etait orpheline.
    Renomme pour rejoindre le vrai net. README ERC mis a jour (0 erreur).
2026-11-11 Resimulation 18,9W avec la fuite de couplage corrigee (k=0,9798 au lieu de 0,99)
    gen_asc.py utilisait la colonne "coupling coefficient" arrondie de la
    datasheet MSD1514 (0,99), impliquant ~0,20uH de fuite -- la moitie de la
    fuite typique publiee directement (0,40uH), deja utilisee telle quelle
    dans 00-intention-conception.md pour le calcul d'energie du clamp D1.
    Corrige : k derive de la fuite publiee (0,40uH), pas de la colonne
    arrondie (les deux sont des mesures "typ" independantes, pas liees par
    L x (1-k^2) avec precision).
    24 points rejoues (envelope 18w9 Schottky+sync, clamp candidates).
    Resultats revises : plafond de surtension 106,8V->107,2V, marge D1 au
    pire cas x5,5 (ancien, faux) -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
